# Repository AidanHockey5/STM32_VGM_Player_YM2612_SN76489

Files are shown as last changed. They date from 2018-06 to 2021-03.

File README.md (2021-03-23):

# This Version of the Project is now Deprecated
This is the old version of the Mega Blaster Project. Please visit this repo for the latest and greatest Mega Blaster 2 source material
https://github.com/AidanHockey5/MegaBlaster2

# Mega Blaster

See this project in action here: https://www.youtube.com/watch?v=WoAp2-gWaLM

For more information, visit: http://www.aidanlawrence.com/megablaster-hardware-sega-genesis-video-game-music-player/

This project is a hardware Video Game Music (VGM) player that uses a genuine YM2612 synthesizer chip + SN76489AN PSG. 
This project is driven by an STM32 "Blue Pill" board, chosen for it's ample speed, I/O, and best of all, price!

Included in this repository is the source code for the project, all of the schematic files, and a completed 
Ki-CAD printed circuit board /w Gerber files. Feel free to produce your own board!

PCB

# Information about the main sound chips and VGM

The YM2612 is a 6-channel FM synthesizer IC that was most prominently featured in the Sega Genesis (AKA Megadrive) home video game console. The YM2612 was also featured in the FM-Towns home computer and the Sega C2 Arcade System.
The YM2612 also had a CMOS alias that is functionally identical named the YM3438.
The SN76489 is a 3-channel + 1 noise channel programmable sound generator (PSG) that was popular with several early video game systems and home computers.
Most notably, the SN76489 was featured in the Sega Master system, the predecessor to the Genesis. To allow for backwards compatibility, Sega included a clone of the SN76489 in their new Genesis consoles.
Programmers and sound designers could leverage the SN76489 to add three more square wave channels to the YM2612's 6-channels of FM synth, creating 9 channels + 1 noise channels in total.
While this player was designed with the Genesis in mind, it can play back any VGM files designed for the Master System, FM-Towns PC, C2 machine, or any other machine that used the YM2612/YM3438 and/or the SN76489.
This project synthesizes music from .VGM files in real time on genuine hardware. There is no emulation here.

VGM stands for Video Game Music, and it is a 44.1KHz logging format that stores real soundchip register information. My player will parse these files and send the data to the appropriate chips. You can learn more about the VGM file format here: http://www.smspower.org/Music/VGMFileFormat

http://www.smspower.org/uploads/Music/vgmspec170.txt?sid=58da937e68300c059412b536d4db2ca0

# SD Card Information
This project is built for full-sized SD cards, but you may use adapters to fit your desired card. You must format your SD card to Fat32 in order for this device to work correctly. Your SD card must only contain uncompressed .vgm files. VGZ FILES WILL NOT WORK! You may download .vgz files and use [7zip](http://www.7-zip.org/download.html) to extract the uncompressed file out of them. Vgm files on the SD card do not need to have the .vgm extension. As long as they contain valid, uncompressed vgm data, they will be read by the program regardless of their name.
You can find VGM files by Googling "myGameName VGM," or by checking out sites like http://vgmrips.net/packs/

# Control Over Serial
You can use a serial connection to control playback features. The commands are as follows:

Command | Result
------------ | -------------
\+ | Next Track
\- | Previous Track
\* | Random Track
\/ | Toggle Shuffle Mode
\. | Toggle Song Looping
r: | Request song
? | What song is playing?
\! | Toggle the OLED display

A song request is formatted as follows: ```r:mySongFile.vgm```
Once a song request is sent through the serial console, an attempt will be made to open that song file. The file must exist on the SD card, and spelling/capitalization must be correct.
Need an easy-to-use serial console? [I've made one here.](https://github.com/AidanHockey5/OpenArduinoSerialConsole)

# Schematic
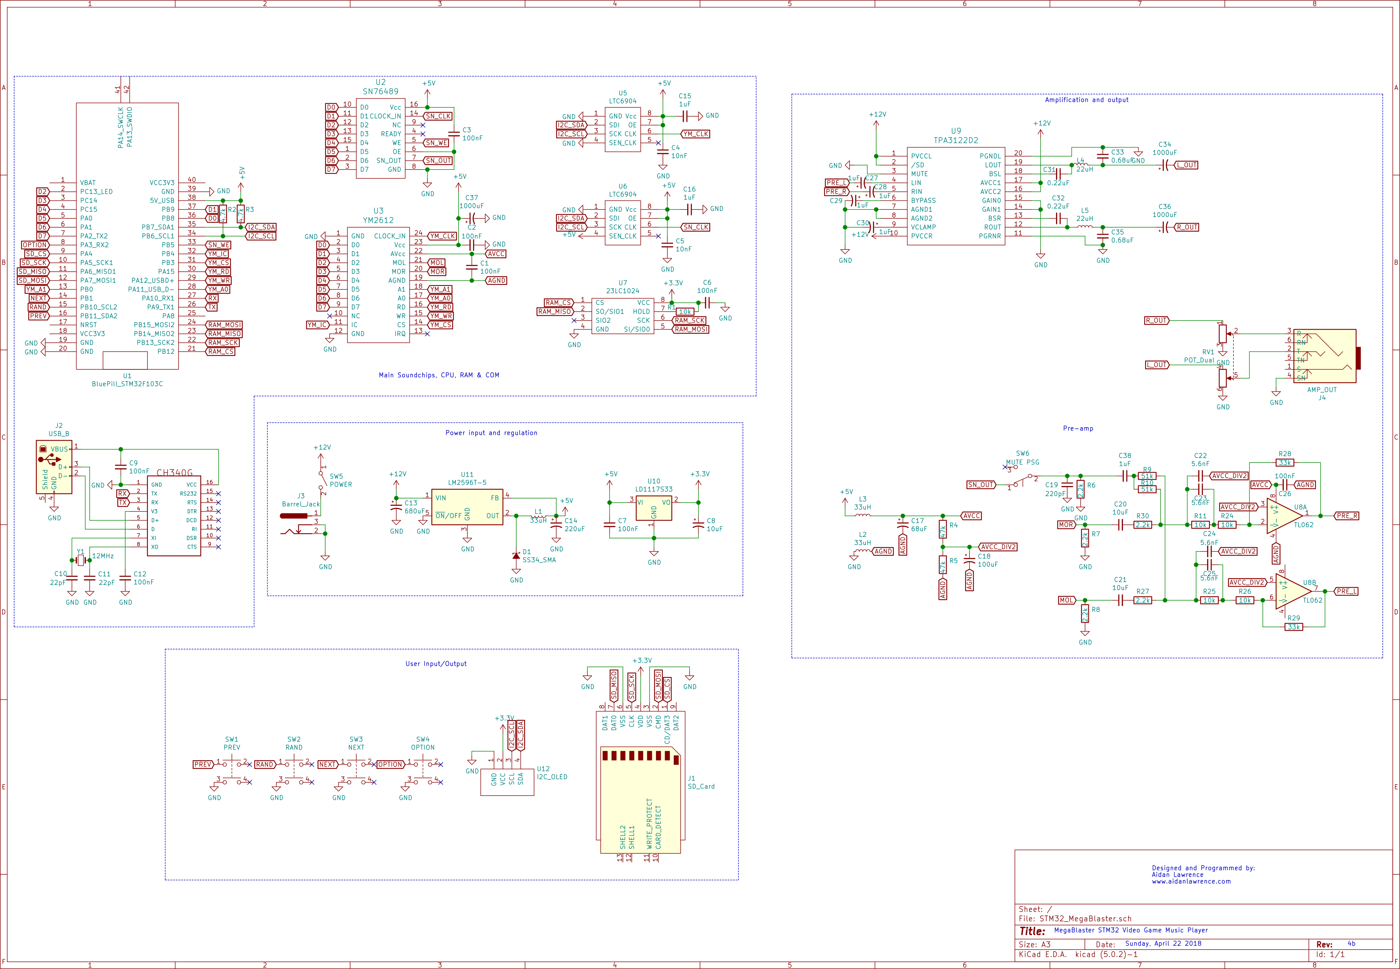
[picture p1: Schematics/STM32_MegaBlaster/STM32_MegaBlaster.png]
Schematic


[PDF](https://github.com/AidanHockey5/STM32_VGM_Player_YM2612_SN76489/raw/master/Schematics/STM32_MegaBlaster/STM32_MegaBlaster.pdf)

[Bill Of Materials (BOM)](https://github.com/AidanHockey5/STM32_VGM_Player_YM2612_SN76489/tree/master/Schematics/STM32_MegaBlaster/BOM)

# Interactive Assembly Guide
[You can view the interactive guide here.](https://www.aidanlawrence.com/wp-content/uploads/2018/09/ibom.html)

Courtesy of the stellar KiCAD plugin, [Interactive HTML BOM](https://github.com/openscopeproject/InteractiveHtmlBom)

Use this guide to help you assemble the Mega Blaster. Hover your cursor over the list of parts and this web page will show you where to place each component. I have included the source HTML file under the [Schematic's BOM folder](https://github.com/AidanHockey5/STM32_VGM_Player_YM2612_SN76489/tree/master/Schematics/STM32_MegaBlaster/BOM) for local viewing. 

# Programming

Programming must be done through the built-in serial port. YOU CAN NOT USE AN STLINK FOR PROGRAMMING.

You have two programming options: Using the flashing tool OR flashing from source.

[DOWNLOAD THE FLASHING TOOL HERE](https://www.aidanlawrence.com/tools/ee/megablaster/MegaFlasher_MB.zip)

Windows users can just use the pre-compiled Flash.exe program to skip worrying about Python installs or dependancies.
All other operating system users can simply run the Flash.py script using Python 3.0+.

Read the Readme file included with the tool for usage instructions and python dependancies.

I have also made a quick video guide on how to program the MegaBlaster from source. It's pretty simple!

https://youtu.be/sSx3_d5n6gs

1) Set the "Bluepill" left jumper to the '1' position.
2) Turn on the MegaBlaster
3) Hit the reset button on the Bluepill board.
4) Open the source code in Visual Studio Code /w the PlatformIO extension.
5) Upload the code using the upload button on the bottom ribbon.
6) Replace the jumper on the Bluepill board to it's original '0' position.

Link to VS Code: https://code.visualstudio.com/

PlatformIO install guide: http://docs.platformio.org/en/latest/ide/vscode.html#installation 

PlatformIO Not finding your serial port? Try opening up your Platformio.ini file and adding the following lines:
```
upload_port = COMX

upload_protocol = serial
```

(Make sure to change 'X' to the number of your COM port that the MegaBlaster is connected to. (I.E. COM4, COM8, COM10, etc.)

# KiCad
The schematic and PCB of this project was made in a nightly version of KiCad 5, specifically, 5.0.0 RC2 (dev-493-gd776eaca8)
Since then, the project has been migrated to KiCAD 5 stable.
Please download the latest stable release of KiCAD 5 here: http://kicad-pcb.org/download/

# YM3438 Support
After a little tinkering, I've managed to get a YM3438 working as a replacement for the YM2612. For those that don't know, the YM3438 is functionally equivalent to the YM2612, but is made using a CMOS process. The YM3438 is pin-compatible but it is not a drop-in replacement since the output impedance is significantly higher. Fortunately, all you need to do to get a YM3438 to work is mod a couple resistors.

Resistor Number | Replace with
------------ | -------------
R7 | LEAVE UNPOPULATED
R8 | LEAVE UNPOPULATED
R6 | 1.2K
R9 | 100K
R10 | 100K
R27 | 33K
R30 | 33K
R28 | 150K
R29 | 150K

WARNING! The final sound output volume will be SIGNIFICANTLY HIGHER with this setup. Be sure to start your YM3438 MegaBlaster at the lowest possible volume before turning on the device and slowly increase the volume to prevent equipment damage and or hearing damage.

Why replace the YM2612 with a YM3438? Well, for one, the YM3438 runs very cool while the YM2612s typically get screaming hot during normal operation. The sound quality is also slightly altered with FM synths typically sounding a little more 'sterile' compared to the YM2612's characteristic grit. PCM sample quality is also significantly improved. Later revisions of the Sega Genesis used an ASIC YM3438 instead of a discrete YM2612, so some users may be more familiar with the likes of the YM3438 than the YM2612. It's all personal preference really.

You can see a YM2612/YM3438 comparison video here: https://www.youtube.com/watch?v=jMHRtriv1wM

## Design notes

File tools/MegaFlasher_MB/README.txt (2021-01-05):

NO DEPENDANCIES OR PYTHON INSTALL REQUIRED FOR WINDOWS EXE

PYTHON DEPENDANCIES:
Python 3.0+
pyserial
requests

Enter the following commands:

pip install pyserial
pip install requests

Run:
python3 Flash.py

----------------------------------------------

Instructions for use:

On the MEGABLASTER DEVICE: Move the left jumper pin at the top of the board to the "UP" position.
It should look like this:
https://www.aidanlawrence.com/wp-content/uploads/2021/01/mb_jumper-scaled.jpg

Plug-in your MEGABLASTER to your computer via USB and apply 12V to the power jack.

Switch the unit ON.

Press the RESET BUTTON.

Run the Flash.exe program OR run Flash.py with Python.

Select the COM port of the MEGABLASTER.

If everything is correct, your system should automatically download the firmware file and flash.

After flashing, replace the jumper's position back to DOWN.

----------------------------------------------

EXE Built with pyinstaller
pyinstaller --onefile Flash.py

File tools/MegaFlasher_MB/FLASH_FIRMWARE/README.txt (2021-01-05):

stm32flash 0.5

This binary is for Microsoft Windows 64-bit

It was built using MinGW-64 from MSYS2 with gcc 5.3.0,
for build instructions please see:
https://sourceforge.net/p/stm32flash/wiki/Build/

Source code:
https://sourceforge.net/p/stm32flash/code/ci/v0.5/tree/

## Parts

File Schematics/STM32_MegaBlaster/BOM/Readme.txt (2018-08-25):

I've tried to keep as many components on Digikey as possible, but obviously, not everything will be on there.
That means that if you'd like a complete order of components, you must have all of the components from the DIGIKEY-BOM.csv file AND the EXTERNAL_BOM_ITEMS.txt list.

For items like resistors: Bog-standard 1/4 watt (the most common sizes you'd normally find in kits) will work, but I tried to track some down on Digikey any ways. 

For items listed on Aliexpress: Shop around and do your research. The links I provided should give you a great head start. Also check sources like eBay for similar goods.
LCSC can also provide parts at a significantly lower price than Digikey, but their selection is not as good. If you order a PCB from JLCPCB, you can ship components from LCSC combined for free.

You can use the Digikey BOM import tool to make this entire process much faster: https://www.digikey.com/BOM
Or you can sign-in to Digikey and view the parts cart here: https://www.digikey.com/short/jf18pj

Also, the 1000uF capacitors (C37, C36, and C34) are actually have 2.5mm pin spacing, but Digikey only had 3.5mm spaced 8mm diameter caps. The fit isn't exactly perfect, but it's close enough to work.
If you can find 1000uF (16V or higher) capacitors that are 8mm in diameter and have 2.5mm pin spacing, I reccomend that you use those for a better fit.

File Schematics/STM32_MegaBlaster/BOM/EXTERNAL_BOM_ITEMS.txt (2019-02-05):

1x - J4 - AMP_OUT - PJ320E_3.5mm_Jack - https://www.aliexpress.com/wholesale?catId=0&initiative_id=SB_20180518120441&SearchText=PJ-320E
1x - RV1 - POT_Dual - LOG-10k DUAL GANG POTENTIOMETER - https://www.adafruit.com/product/3394
1x - U4 - CH340G - https://lcsc.com/product-detail/USB_CH340G_C14267.html 
1x - U1 - STM32 Bluepill Board - https://www.aliexpress.com/wholesale?catId=0&initiative_id=SB_20180518120532&SearchText=STM32F103C8T6
1x - U2 - SN76489AN - https://www.aliexpress.com/wholesale?catId=0&initiative_id=SB_20180518120553&SearchText=SN76489
1x - U3 - YM2612 - https://www.aliexpress.com/wholesale?catId=0&initiative_id=SB_20180518120658&SearchText=YM2612
1x - U12 - I2C OLED 1.3in. SH1106 - https://www.aliexpress.com/wholesale?catId=0&initiative_id=SB_20180518121221&SearchText=I2C+OLED+1.3

[[[OLED WARNING! Check for SH1106, not SSD1306. Check pin order! Pin order must be: GND, VCC, SCL(SCK), SDA. Most OLEDs feature a set of jumper resistors on the back to adjust these pins should you order a display with an incorrect pin configuration.]]]

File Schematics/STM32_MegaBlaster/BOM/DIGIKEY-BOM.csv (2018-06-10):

Manufacturer Part Number | Manufacturer | Digi-Key Part Number | Customer Reference | Reference Designator | Packaging | Part Status | Quantity | Unit Price | Extended Price | Quantity Available | Mfg Std Lead Time | Description | RoHS Status | Lead Free Status | REACH Status
UPJ1E680MED1TD | Nichicon | 493-5039-1-ND |  |  | Cut Tape (CT) | Active | 1 | 0.31000 | $0.31 | 4990 | 18 Weeks | CAP ALUM 68UF 20% 25V RADIAL | RoHS Compliant | Lead free | REACH Unaffected
RDE5C1H562J1K1H03B | Murata Electronics North America | 490-8704-ND |  |  | Bulk | Active | 4 | 0.49000 | $1.96 | 1129 | 11 Weeks | CAP CER 5600PF 50V NP0 RADIAL | RoHS Compliant | Lead free | REACH Unaffected
AIUR-16-330K | Abracon LLC | AIUR-16-330K-ND |  |  | Box | Active | 3 | 0.78000 | $2.34 | 868 | 11 Weeks | FIXED IND 33UH 800MA 90 MOHM TH | RoHS Compliant | Lead free | REACH Unaffected
16ZLH680MEFC10X12.5 | Rubycon | 1189-1150-ND |  |  | Bulk | Active | 1 | 0.43000 | $0.43 | 6103 | 17 Weeks | CAP ALUM 680UF 20% 16V RADIAL | RoHS Compliant | Lead free | REACH Unaffected
0670688011 | Molex, LLC | WM12785-ND |  |  | Tube | Active | 1 | 2.06000 | $2.06 | 1590 | 12 Weeks | USB B CONN WITH KINK BOARD LOCK | RoHS Compliant | Lead free | REACH Unaffected
1825115-1 | TE Connectivity ALCOSWITCH Switches | 450-1598-ND |  |  | Bulk | Active | 2 | 0.98000 | $1.96 | 3119 | 4 Weeks | SWITCH SLIDE SPDT 250MA 125V | RoHS Compliant | Lead free | Not Available
2041021-4 | TE Connectivity AMP Connectors | A101492CT-ND |  |  | Cut Tape (CT) | Active | 1 | 3.44000 | $3.44 | 2777 | 11 Weeks | CONN SD CARD PUSH-PULL R/A SMD | RoHS Compliant | Lead free | Not Available
PJ-002A | CUI Inc. | CP-002A-ND |  |  | Bag | Active | 1 | 0.60000 | $0.60 | 113742 | Not Available | CONN PWR JACK 2X5.5MM SOLDER | RoHS Compliant | Lead free | Not Available
TL062CP | Texas Instruments | 296-1771-5-ND |  |  | Tube | Active | 1 | 0.69000 | $0.69 | 3889 | 13 Weeks | IC OPAMP JFET 1MHZ 8DIP | RoHS Compliant | Lead free | REACH Unaffected
K104Z15Y5VF5TL2 | Vishay BC Components | BC1160CT-ND |  |  | Cut Tape (CT) | Active | 8 | 0.19000 | $1.52 | 78547 | 8 Weeks | CAP CER 0.1UF 50V Y5V RADIAL | RoHS Compliant | Lead free | Not Available
K103K15X7RF5TL2 | Vishay BC Components | BC1078CT-ND |  |  | Cut Tape (CT) | Active | 2 | 0.19000 | $0.38 | 9972 | 8 Weeks | CAP CER 10000PF 50V X7R RADIAL | RoHS Compliant | Lead free | Not Available
UMA1C100MDD1TP | Nichicon | 493-10458-1-ND |  |  | Cut Tape (CT) | Active | 1 | 0.28000 | $0.28 | 7221 | 21 Weeks | CAP ALUM 10UF 20% 16V RADIAL | RoHS Compliant | Lead free | REACH Unaffected
K220J15C0GF5TL2 | Vishay BC Components | BC1005CT-ND |  |  | Cut Tape (CT) | Active | 2 | 0.21000 | $0.42 | 93566 | 8 Weeks | CAP CER 22PF 50V C0G/NP0 RADIAL | RoHS Compliant | Lead free | Not Available
UVY1C221MED1TD | Nichicon | 493-12895-1-ND |  |  | Cut Tape (CT) | Active | 1 | 0.31000 | $0.31 | 4437 | 18 Weeks | CAP ALUM 220UF 20% 16V RADIAL | RoHS Compliant | Lead free | REACH Unaffected
FG28X7R1E105KRT06 | TDK Corporation | 445-173583-1-ND |  |  | Cut Tape (CT) | Active | 3 | 0.32000 | $0.96 | 4648 | 16 Weeks | CAP CER 1UF 25V X7R RADIAL | RoHS Compliant | Lead free | REACH Unaffected
ECA-1CM101 | Panasonic Electronic Components | P5138-ND |  |  | Bulk | Active | 1 | 0.22000 | $0.22 | 5184 | 15 Weeks | CAP ALUM 100UF 20% 16V RADIAL | RoHS Compliant | Lead free | REACH Unaffected
FA28C0G2E221JNU06 | TDK Corporation | 445-174276-1-ND |  |  | Cut Tape (CT) | Active | 1 | 0.50000 | $0.50 | 5597 | 16 Weeks | CAP CER 220PF 250V NP0 RADIAL | RoHS Compliant | Lead free | REACH Unaffected
FG24X7R1A106KRT06 | TDK Corporation | 445-173370-1-ND |  |  | Cut Tape (CT) | Active | 2 | 0.58000 | $1.16 | 1831 | 16 Weeks | CAP CER 10UF 10V X7R RADIAL | RoHS Compliant | Lead free | REACH Unaffected
UMF1V010MDD1TP | Nichicon | 493-10230-1-ND |  |  | Cut Tape (CT) | Active | 4 | 0.45000 | $1.80 | 2110 | 21 Weeks | CAP ALUM 1UF 20% 35V RADIAL | RoHS Compliant | Lead free | REACH Unaffected
FG24X7R1H224KNT06 | TDK Corporation | 445-173377-1-ND |  |  | Cut Tape (CT) | Active | 2 | 0.29000 | $0.58 | 4783 | 16 Weeks | CAP CER 0.22UF 50V X7R RADIAL | RoHS Compliant | Lead free | REACH Unaffected
FA28X7R1H683KNU06 | TDK Corporation | 445-175032-1-ND |  |  | Cut Tape (CT) | Active | 2 | 0.41000 | $0.82 | 3940 | 16 Weeks | CAP CER 0.068UF 50V X7R RADIAL | RoHS Compliant | Lead free | REACH Unaffected
CDBA140-G | Comchip Technology | 641-1015-1-ND |  |  | Cut Tape (CT) | Active | 1 | 0.37000 | $0.37 | 339890 | 16 Weeks | DIODE SCHOTTKY 40V 1A DO214AC | RoHS Compliant | Lead free | REACH Unaffected
RNF14FTD10K0 | Stackpole Electronics Inc. | RNF14FTD10K0CT-ND |  |  | Cut Tape (CT) | Active | 5 | 0.10000 | $0.50 | 182883 | 13 Weeks | RES 10K OHM 1/4W 1% AXIAL | RoHS Compliant | Lead free | REACH Unaffected
CF14JT4K70 | Stackpole Electronics Inc. | CF14JT4K70CT-ND |  |  | Cut Tape (CT) | Active | 2 | 0.10000 | $0.20 | 299143 | 14 Weeks | RES 4.7K OHM 1/4W 5% AXIAL | RoHS Compliant | Lead free | REACH Unaffected
CF14JT47K0 | Stackpole Electronics Inc. | CF14JT47K0CT-ND |  |  | Cut Tape (CT) | Active | 2 | 0.10000 | $0.20 | 186504 | 14 Weeks | RES 47K OHM 1/4W 5% AXIAL | RoHS Compliant | Lead free | REACH Unaffected
CF14JT2K20 | Stackpole Electronics Inc. | CF14JT2K20CT-ND |  |  | Cut Tape (CT) | Active | 5 | 0.10000 | $0.50 | 144923 | 14 Weeks | RES 2.2K OHM 1/4W 5% AXIAL | RoHS Compliant | Lead free | REACH Unaffected
CF14JT51K0 | Stackpole Electronics Inc. | CF14JT51K0CT-ND |  |  | Cut Tape (CT) | Active | 2 | 0.10000 | $0.20 | 19213 | 14 Weeks | RES 51K OHM 1/4W 5% AXIAL | RoHS Compliant | Lead free | REACH Unaffected
CF14JT33K0 | Stackpole Electronics Inc. | CF14JT33K0CT-ND |  |  | Cut Tape (CT) | Active | 2 | 0.10000 | $0.20 | 185584 | 14 Weeks | RES 33K OHM 1/4W 5% AXIAL | RoHS Compliant | Lead free | REACH Unaffected
B3F-1060 | Omron Electronics Inc-EMC Div | SW1177-ND |  |  | Bulk | Active | 4 | 0.34000 | $1.36 | 2711 | 11 Weeks | SWITCH TACTILE SPST-NO 0.05A 24V | RoHS Compliant | Lead free | Not Available
A 24-LC-TT | Assmann WSW Components | AE10001-ND |  |  | Tube | Active | 1 | 0.35000 | $0.35 | 6647 | 20 Weeks | CONN IC DIP SOCKET 24POS TIN | RoHS Compliant | Lead free | REACH Unaffected
A 16-LC-TT | Assmann WSW Components | AE9992-ND |  |  | Tube | Active | 1 | 0.25000 | $0.25 | 38380 | 20 Weeks | CONN IC DIP SOCKET 16POS TIN | RoHS Compliant | Lead free | REACH Unaffected
A 08-LC-TT | Assmann WSW Components | AE9986-ND |  |  | Tube | Active | 2 | 0.18000 | $0.36 | 87482 | 20 Weeks | CONN IC DIP SOCKET 8POS TIN | RoHS Compliant | Lead free | REACH Unaffected
A 20-LC-TT | Assmann WSW Components | AE9998-ND |  |  | Tube | Active | 1 | 0.29000 | $0.29 | 44887 | 20 Weeks | CONN IC DIP SOCKET 20POS TIN | RoHS Compliant | Lead free | REACH Unaffected
LTC6904CMS8#PBF | Linear Technology/Analog Devices | LTC6904CMS8#PBF-ND |  |  | Tube | Active | 2 | 4.31000 | $8.62 | 1595 | 8 Weeks | IC OSC SILICON PROG 8-MSOP | RoHS Compliant | Lead free | REACH Unaffected
23LC1024-I/P | Microchip Technology | 23LC1024-I/P-ND |  |  | Tube | Active | 1 | 2.22000 | $2.22 | 297 | 5 Weeks | IC SRAM 1MBIT 20MHZ 8DIP | RoHS Compliant | Lead free | REACH Unaffected
TPA3122D2N | Texas Instruments | 296-23375-5-ND |  |  | Tube | Active | 1 | 3.31000 | $3.31 | 421 | 6 Weeks | IC AMP AUDIO PWR 15W STER 20DIP | RoHS Compliant | Lead free | REACH Unaffected
LD1117S33TR | STMicroelectronics | 497-1242-1-ND |  |  | Cut Tape (CT) | Active | 1 | 0.42000 | $0.42 | 0 | Not Available | IC REG LINEAR 3.3V 800MA SOT223 | RoHS Compliant | Lead free | Not Available
LM2596S-5.0/NOPB | Texas Instruments | LM2596S-5.0/NOPB-ND |  |  | Tube | Active | 1 | 5.72000 | $5.72 | 0 | 30 Weeks | IC REG BUCK 5V 3A TO263-5 | RoHS Compliant | Contains lead | REACH Unaffected
ECS-120-20-4 | ECS Inc. | X227-ND |  |  | Bulk | Active | 1 | 0.69000 | $0.69 | 1635 | 9 Weeks | CRYSTAL 12.0000MHZ 20PF T/H | RoHS non-compliant | Contains lead | REACH Unaffected
UHV1C102MPD6 | Nichicon | 493-16434-ND |  |  | Bulk | Active | 3 | 0.65000 | $1.95 | 677 | 20 Weeks | CAP ALUM 1000UF 20% 16V RADIAL | RoHS Compliant | Lead free | REACH Unaffected
RLB1014-222KL | Bourns Inc. | RLB1014-222KL-ND |  |  | Bag | Active | 2 | 0.43000 | $0.86 | 1019 | 20 Weeks | FIXED IND 2.2MH 110MA 8.4 OHM TH | RoHS Compliant | Lead free | REACH Unaffected

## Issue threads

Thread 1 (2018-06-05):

OSH Park Unsupported Drilled Slots

sparksterz, 2018-06-05:
Hey, I was looking to build one of these, but having no knowledge of PCB layout and tools to generate them with I'm wondering if this is something to be concerned about.

Unfortunately they don't really give much info on which slots...and it's flagged as just a warning. I'm able to generate this by uploading the zipped gerber files. using the kicad_pcb file directly doesn't seem compatible. I assume due to the version of kicad being newer? Not sure.

Here is the information they give me from the zipped gerber files:

Processing information
* Processing Megablaster_Gerber.zip as KiCad ZIP file.
* 2 layer board of 5.46x3.61 inches.
* Your project contains 2 drill files, we've merged them. ["STM32_MegaBlaster-NPTH.drl", "STM32_MegaBlaster-PTH.drl"]

Warning (non-critical)
* Detected unsupported drilled slots.

As far as I can tell by their thumbnail board renders this might be the slots near the DC power jack and/or maybe the audio jack? They seem to look a bit strange on their generated image. Here's the [link to the image that was generated](https://644db4de3505c40a0444-327723bce298e3ff5813fb42baeefbaa.ssl.cf1.rackcdn.com/67f2c8f53406d2f81542bcc66bbe4da2.png)

Is there another preferred vendor to use? I know a minor amount about electronics from bread board type work, but nothing about prefabricated PCBs.

AidanHockey5, 2018-06-05:
Hello Brian!

Yep! It's a good thing you caught that because your DC jack wouldn't fit
with holes like that!

I recommend using JLCPCB - it's who I went with for this project. They'll
give your more boards for less money to boot. The zipped Gerber files I
created are to their specifications, so they should work without a hitch.

Let me know if you have any more questions!

-Aidan

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

Closed 2018-06-07.

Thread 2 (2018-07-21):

Some tunes with heavy (drum) samples usage slow down the replay speed

rylecqfd, 2018-07-21:
Hi

It seems that some tunes that make heavy use of (drum) samples have their speed slowed down each time a sample is played.

Here is one example:  [Matt Furniss - The Terminator](http://project2612.org/download.php?id=181).

AidanHockey5, 2018-07-22:
Yep, that is a known limitation of the hardware. The tracks you have picked are by an artist who is known for pushing the Genesis' musical hardware to its limits, so my little player is probably not going to be able to keep up with the heavy usage of PCM samples.

Most VGM files will play back at full speed regardless of their PCM sampling. Just a few particular PCM-heavy tracks saturate the data bus and prevent full-speed playback.

One particular torture test that I like to use is actually Green Hill Zone from Sonic the Hedgehog. That track's PCM drums often brought my previous prototypes to their knees. The MegaBlaster can keep up for the most part, but the tempo still lags behind just a bit. I'd be interested to see if anybody could modify the firmware to write PCM samples faster than what I have here!

natarii, 2018-10-21:
This is an old issue, but I briefly looked at your code, and while I don't have any STM32 hardware to test this on, I suspect you are running into this problem due to the overhead of setting up and tearing down the SPI transfer from the SRAM for every sample.

I am working on a similar project and it is able to play these files without any speed issues. My solution is instead of using a large chunk of RAM, use relatively small buffers (a few K) and load the VGM file using separate streams into two FIFOs: one for raw VGM commands, the other for the attached PCM data. When reading an 0x8n command from the file, calculate the offset of that sample and read it into the PCM FIFO before inserting the 0x8n command into the VGM FIFO. This way, during playback, when you hit an 0x8n you can just pull the first sample out of the PCM FIFO.

Possible complications:
- Your code will likely need some reworking, as your playback loop appears to directly read the file and then write to the chip with no buffering in between.
- I believe the SdFat library uses a single SD card buffer, rather than one per File object. You may need to implement your own buffer to wrap around File.read(), otherwise performance will get killed from all the seeking. A multiple of the SD card's sector size may be a good starting point.
- From your schematic, the SD card is hooked up in 1-bit mode. I don't know offhand if this is fast enough to playback PCM data in realtime. 4-bit mode certainly is...

That being said, it's probably worth dealing with this to get the ability to play "busy" VGMs, and also VGMs that have more PCM data than would fit in the SRAM.

Here are some demo videos of playing a few of the tracks mentioned in this issue. Just recorded real quickly with my phone camera, but you get the idea. This technique is being used.
https://youtu.be/QawYF8nzBoE
https://youtu.be/OeX5HKd4tyY

Links to my project source. The relevant parts will be in loader.c and driver.c: https://git.agiri.ninja/natalie/megagrrl/blob/master/main/loader.c
https://git.agiri.ninja/natalie/megagrrl/blob/master/main/driver.c

If you contact me off GitHub I can also provide further pointers on implementing this, or VGM DAC stream control support!

AidanHockey5, 2018-10-26:
I think there is a chance that performance could be significantly improved via software, but it would require a pretty extensive rewrite. Implementing a buffering system like @natarii would be pretty tricky, but it would likely drastically improve PCM playback speeds.
I'm still of the opinion though that I'm a bit hardware limited, so I may need to rethink some of my board layout too.
Either way though, I think rewriting the software for this project is a definite goal of mine, so I'll see what I can do in that regard.

piklz, 2018-10-26:
That would be awesome both of you working together would be neat ! I'm going to order your bom/pcs etc  anyway and make the current version so hopefully any improvements will be greatly appreciated!

natarii, 2018-10-26:
Hi, sorry, I didn't check GitHub for a few days.

I ordered an STM32 Blue Pill board to play with. I didn't realize it had "only" 20K of RAM, but I have a feeling this is still doable on it. My earlier experiments in this project were on an ATmega2560, a Teensy 3.6, and finally an ESP32, so yeah I've gone through several revisions as well. Everything I've done was also doable on the Teensy 3.6, just a bit hackier because it doesn't have the luxury of the ESP32's second core and all the FreeRTOS queues and stuff to pass data around.

Unsure about whether 1-bit SD mode will be fast enough to do this in realtime. A lot of VGMs seem to have tons of redundant register writes when playing PCM, and you may be looking at a requirement of 150KB/s+ read speed to be able to handle it. I think this is well within the theoretical read speed, but it may work out differently in practice, and/or be dependent on the specific card. Getting rid of the SPI RAM may free up enough IOs to use the card in 4-bit mode, assuming there are no restrictions on which pins can be used for that. (Lack of IOs pushed me to use shift registers for the sound chip bus on the ESP32, but I'm also hitting them pretty fast at 20+ MHz)

You'll probably want to move the actual chip output stuff into a timer interrupt, and either get a library or write from scratch some ISR-safe FIFOs. You can also just disable timer interrupts when sticking new data into the FIFOs although that isn't quite as clean.

If you want to collab on anything, let me know, I'd enjoy that. I can also get you a schematic of my hardware, only haven't put it in git yet because there are a few minor errors that need to be fixed, although they're related to power supply stuff rather than anything VGM-related

AidanHockey5, 2018-10-26:
I'd love to collaborate! I'm really interested in seeing how you'd approach this on a blue-pill board. The RAM requirements really make buffering systems tough to pull off. I think the ESP32 has something along the lines of 520KB of RAM (wow) which would be an absolute luxury for me. Buffering out FM+PSG data shouldn't really be an issue, but as always, once PCM samples come into play, the game changes a bit.
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
AidanHockey5, 2018-11-05:
Hey everyone, I have just rewritten the firmware from scratch. Version 2 is up and ready to go.
Here are the notes on my changes: https://github.com/AidanHockey5/STM32_VGM_Player_YM2612_SN76489/pull/3

Playback speed has been significantly improved, though, there are still limitations with the hardware that are keeping me from playing songs like The Terminator tracks listed above. I simply don't have enough RAM to keep everything cached away in buffers and since my SD card is in 1-bit mode, I can't replenish the buffers fast enough to keep in time. Therefore, unless there is someone out there that can perform some serious magic, I think this is about as good as it's going to get for this iteration of the hardware.

For all the other tracks with more reasonable PCM sessions, this new version is night-and-day better!

krsshtx, 2019-12-30:
Hi Aidan!
Can you check playback of this ost?
https://project2612.org/details.php?id=124

AidanHockey5, 2019-12-30:
Hello krsshtx,

Battletoads is infamously difficult to play back, so it's unlikely that my player would be able to render it without any slowdown. A project that _can_ handle that OST would be Natalie's MegaGRRL player! https://kunoichilabs.dev/

krsshtx, 2019-12-31:
> Battletoads is infamously difficult to play back, so it's unlikely that my player would be able to render it without any slowdown.

Looks like it's more complex - beeping on some tracks and tempo drift on others .

I have another strange issue. Clicking sound instead of drums in high seas havoc o_O
No drums at all.

https://project2612.org/details.php?id=343

krsshtx, 2020-01-05:
case 0x4F:
case 0x50:
case 0x52:
case 0x53:
***
return 1
1:  1/44100 = 22675,736961451ns

ym2203 pdf:
Address set-up time 10ns min
Write data setup time 100ns min
Write pulse write width 200ns min

krsshtx, 2020-01-12:
re-mix
https://github.com/krsshtx/YM

AidanHockey5, 2021-01-01:
#6
At long last with much trial and error, this issue has been fixed. The reason behind it was mostly due to a misunderstanding I had with how VGM data was supposed to be parsed. Instead of literally taking one sample every 1/44100th of a second, you are supposed to write entire blocks of data to the chips as soon as possible and ONLY tick delay commands at 44100Hz.

Early tests seem stable enough. Even write-heavy tracks like ones from The Terminator OST seem to work admirably.

Sorry for the delay on fixing this! I thought it couldn't be fixed.

Hey, at least @natarii was the best thing to come out of this issue, haha.

krsshtx, 2021-03-08:
>I thought it couldn't be fixed.

Хорошо, что не сдался.
Как насчёт ym2608?

krsshtx, 2021-03-10:
From the other side...

As I thought you've abandoned your project and I had a non-working properly device which I really loved I had no choice but to re-mix your code.

Your words "A project that can handle that OST would be Natalie's MegaGRRL player!" confused me a lot. Dissapointed a lot.
M68K/Z80 was able, but STM32 can't. Lets see..

I'am not a programmer. And had no knowledge in arduino ide and stm32 at all.
After a lot of building/uploading and making lpt 2612 device to test i've made a working build which played high seas havoc, rocket knight adventures, terminator and even battletoads which you've mentioned as unplayable. It took much time.
Your code was:

 if(waitSamples == 0 && !samplePlaying)
  {
    samplePlaying = true;
    waitSamples += parseVGM();

Mine:

 while(waitSamples == 0 )
  {
   waitSamples += parseVGM();
   waitstate=false;

Your:

    case 0x52:
    {
    uint8_t addr = readBuffer();
    uint8_t data = readBuffer();
    ym2612.Send(addr, data, 0);
    }
    return 1;
    case 0x53:
    {
    uint8_t addr = readBuffer();
    uint8_t data = readBuffer();
    ym2612.Send(addr, data, 1);
    }
    return 1;

Mine:

     case 0x52:
    {
     addr = readBuffer();
     data = readBuffer();
     ym2612.Read();
    ym2612.Send(addr, data, 0);

    }
    return 0;
    case 0x53:
    {
     addr = readBuffer();
     data = readBuffer();
        ym2612.Read();
    ym2612.Send(addr, data, 1);

    }
    return 0;

It was even neccesary to make ym_read function. Because it became too fast.

And now you've changed your mind telling "@natarii was the best thing" and started to sell it.

I am very impressed not to say more.

Closed 2021-01-01.

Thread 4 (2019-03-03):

Build issues (Win 10 x64) Missing build steps?

sparksterz, 2019-03-03:
I've recently assembled my board but am unable to build/upload the project. I have the latest VS Code and recently installed Platform IO. I've made/logged in with my account, but when trying to run a build or upload I am having issues.

The first of which was that `U8g2lib.h` was not recognized. Within platform io I downloaded u8g2 and that seems to have resolved that issue. The other however I'm unsure of. They all seem related but I don't understand what the errors mean.

Here's the error console

```
Processing genericSTM32F103C8 (platform: ststm32@~4.5.0; board: genericSTM32F103C8; framework: arduino)
-----------------------------------------------------------------------------------------------
Verbose mode can be enabled via `-v, --verbose` option
CONFIGURATION: https://docs.platformio.org/page/boards/ststm32/genericSTM32F103C8.html
PLATFORM: ST STM32 > STM32F103C8 (20k RAM. 64k Flash)
HARDWARE: STM32F103C8T6 72MHz 20KB RAM (64KB Flash)
DEBUG: CURRENT(blackmagic) EXTERNAL(blackmagic, jlink, stlink)
Library Dependency Finder -> http://bit.ly/configure-pio-ldf
LDF MODES: FINDER(chain) COMPATIBILITY(soft)
Collected 33 compatible libraries
Scanning dependencies...
Dependency Graph
|-- <Wire> 1.0
|-- <U8g2> 2.26.1
|   |-- <Wire> 1.0
|   |-- <SPI> 1.0
|-- <SPI> 1.0
|-- <SdFat> 1.0.3
|   |-- <SPI> 1.0
Compiling .pioenvs\genericSTM32F103C8\src\Bus.cpp.o
Compiling .pioenvs\genericSTM32F103C8\src\LTC6904.cpp.o
Compiling .pioenvs\genericSTM32F103C8\src\SN76489.cpp.o
Compiling .pioenvs\genericSTM32F103C8\src\SPIRAM.cpp.o
Compiling .pioenvs\genericSTM32F103C8\src\YM2612.cpp.o
Compiling .pioenvs\genericSTM32F103C8\src\main.cpp.o
Compiling .pioenvs\genericSTM32F103C8\lib980\Wire\SoftWire.cpp.o
Compiling .pioenvs\genericSTM32F103C8\lib980\Wire\Wire.cpp.o
In file included from c:\users\bking\.platformio\packages\toolchain-gccarmnoneeabi\arm-none-eabi\include\stdlib.h:19,
from c:\users\bking\.platformio\packages\toolchain-gccarmnoneeabi\arm-none-eabi\include\c++\8.2.1\cstdlib:75,
from c:\users\bking\.platformio\packages\toolchain-gccarmnoneeabi\arm-none-eabi\include\c++\8.2.1\stdlib.h:36,
from C:\Users\bking\.platformio\packages\framework-arduinoststm32\STM32F1\cores\maple/wirish.h:41,
from C:\Users\bking\.platformio\packages\framework-arduinoststm32\STM32F1\cores\maple/Arduino.h:30,
from src\LTC6904.cpp:2:
C:\Users\bking\.platformio\packages\framework-arduinoststm32\STM32F1\system\libmaple/stm32f1/include/series/gpio.h:489:15: error: duplicate 'inline'
static inline __always_inline void afio_exti_select(exti_num exti, exti_cfg port) {
^~~~~~~~~~~~~~~
C:\Users\bking\.platformio\packages\framework-arduinoststm32\STM32F1\system\libmaple\include/libmaple/nvic.h:112:15: error: duplicate 'inline'
static inline __always_inline void nvic_globalirq_enable() {
^~~~~~~~~~~~~~~
C:\Users\bking\.platformio\packages\framework-arduinoststm32\STM32F1\system\libmaple\include/libmaple/nvic.h:119:15: error: duplicate 'inline'
static inline __always_inline void nvic_globalirq_disable() {
^~~~~~~~~~~~~~~
C:\Users\bking\.platformio\packages\framework-arduinoststm32\STM32F1\cores\maple/ext_interrupts.h:109:15: error: duplicate 'inline'
static inline __always_inline void interrupts() {
^~~~~~~~~~~~~~~
C:\Users\bking\.platformio\packages\framework-arduinoststm32\STM32F1\cores\maple/ext_interrupts.h:123:15: error: duplicate 'inline'
static inline __always_inline void noInterrupts() {
^~~~~~~~~~~~~~~
In file included from c:\users\bking\.platformio\packages\toolchain-gccarmnoneeabi\arm-none-eabi\include\stdlib.h:19,
from c:\users\bking\.platformio\packages\toolchain-gccarmnoneeabi\arm-none-eabi\include\c++\8.2.1\cstdlib:75,
from c:\users\bking\.platformio\packages\toolchain-gccarmnoneeabi\arm-none-eabi\include\c++\8.2.1\stdlib.h:36,
Cfompiling .pioenvs\genericSTM32F103C8\lib980\Wire\utility\WireBase.cpp.orom C:\Users\bking\.platformio\packages\framework-arduinoststm32\STM32F1\cores\maple/wirish.h:41,
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
AidanHockey5, 2019-03-03:
So I checked the pinout and MCU, both match up with the original bluepill board, so that MCU should work fine. Attached is a zip file containing a STM32flash-based uploader that you can use to manually apply the firmware to your board without compiling with PIO. I'm still stumped, but this should at least let you test your hardware.

After unzipping,
1) Simply connect your board and reset it with the programming pin set like normal.
2) Double-click `UPLOAD.bat`
3) It will ask you for a COM port to target. For example, my MegaBlaster is on COM24, so I'll just type in `COM24`. Make sure COM is in all caps and that there are no spaces.
4) The tool should manually begin to upload the precompiled firmware.

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

[STM32_Upload_Tool.zip](https://github.com/AidanHockey5/STM32_VGM_Player_YM2612_SN76489/files/2923758/stm32flash-0.5-win64.zip)

sparksterz, 2019-03-04:
Aidan...YOU'RE THE GOD DAMN BEST!

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

I forked the repo, and I'm going to see if I can figure out or resolve the issues I have building. I noticed the file size of mine came out to be 61kb versus your provided one which was 59kb...so, something is definitely different. I guess I'll have to try and dig into why ststm32 4.5.0 doesn't work on my box. I'm not sure what you want to do with this bug, feel free to close it if you'd like. If someone else comes along with a similar issue maybe it would be worth reopening then.

AidanHockey5, 2019-03-04:
Yeah!! Awesome, glad to see that your hardware is working and that you were
able to get a successful flash.

This compile bug is weird to me. I'm not entirely satisfied and I wish I
knew what was wrong with your copy of the code. If another person comes
along and has the same issue, I'll be willing to drop in again and lend a
hand. If I make any significant changes to the firmware in the future and
you're still having compile issues, I'll post an updated version of the
precompiled bin.

Alright, so once you're all flashed up, make sure you set the programming
jumper back to 0 so the code stays on the device. Also, it looks like your
PSG switch is set to 0, switch it up to 1 to enable it.

Feel free to drop by any time if you have any more issues!

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

sparksterz, 2019-03-04:
Oh, good to know on the PSG. I didn't have a chance to really listen to much this morning before leaving for work. Because the interactive guide labeled it as "Mute PSG" I assumed 0 was not muted.

sparksterz, 2019-03-08:
Yeah - I tried digging into this for about 3 hours today while being significantly out of my element in terms of dev environment, but anything that I found would either compile and then not run - or I'd find the ever helpful advice of "Point the platform version at the latest in git" followed by "Yep, that worked" which, does not in this case.

I think my problem could be 2 fold. A problem with platform io, and also a problem with the libraries in ststm32...but I'm more just thoroughly confused than anything else right now. I somehow managed to mess up my environment enough that my include paths are entirely bogus and nothing can be found. Maybe I'll try this in an Ubuntu VM and see if I can avoid a headache that way now that I know if I can build it, I still push from Windows if I needed to.

AidanHockey5, 2019-03-08:
So I decided to bring out an old computer of mine that was running Windows 10 x64 and has never had VS Code or PlatformIO installed on it before.
I installed both and cloned the repo. Sure enough, once I opened the project and compiled, I was met with the same wall of `inline` errors.

After playing around with the versions a little, I determined that version `ststm32@~3.8.0` was the highest version that would compile without errors. I uploaded the code to my MegaBlaster and sure enough, it worked like a charm.

Why does my desktop with version 4.5.0 compile fine and this old computer only compile with version 3.8.0? I frankly have no idea. It seems super odd to me.

Anyways, I've pushed the change to 3.8.0 to master. Go ahead and give it a shot and let me know if anything changes!

sparksterz, 2019-03-09:
Yep @AidanHockey5 you've done it again! I can now build and deploy from my machine. Awesome stuff. Now I can actually tinker around a bit with the code and maybe debug some interesting issues I've noticed over the serial port. I'm excited! Hands on learning is my favorite :)

I've learned a few things as well, turns out not all SN76489AN chips are made equal. I put 3 different chips in the socket before finding one that had what I felt the proper pitch and volume levels. Good call on adding sockets for those chips!

AidanHockey5, 2019-03-09:
Great! Glad to hear it's finally working for you. Have fun and happy hacking!

Closed 2019-03-04.

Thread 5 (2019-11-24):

sd mount failed!

agentxxxxxx, 2019-11-24:
oled displays SD MOUNT FAILED!. I had checked all of the sd slot connetions and they are ok. what else should I check?

AidanHockey5, 2019-11-24:
Hello!

An SD card failing to mount could be for a number of reasons.

Have you made sure that the SD card is formatted as FAT32?

Are your VGM files uncompressed? (You can’t use VGZ files, you have to extract the VGM inside of them)

Are the pins inside of your SD socket in good condition?

Did you build this as a breadboard prototype? Some cheap SD card adapters are not designed properly and will never mount correctly.

Have you just recently programmed your board? If so, unplug the board from power, then plug the board back in. SD cards almost never mount after a programming cycle.

agentxxxxxx, 2019-11-25:
thanks for your supports! I had solved it. I wired the sd card pin directly to the stm32 board and it worked. the SD slot might be broken internal.

Thanks for your excellent project! It's wonderful!!

Closed 2019-11-25.

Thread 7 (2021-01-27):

Standalone flasher not working

CornBrown, 2021-01-27:
The error i get is that there are python files missing in c:\users\aiden\....    and wont run    (windows 7 64bit)    Everything is working in win10

AidanHockey5, 2021-01-27:
Hello,

Windows 7 has reached its end of life (EoL) and is therefore unsupported.

I could not recreate your issue on Windows 10. I spooled up a fresh Windows 10 VM with a username that is not "Aidan" and I managed to flash the firmware just fine.
* Make sure the board is receiving 12V and is powered on.
* Make sure that you've got the CH340 drivers installed. You can download them here:
https://cdn.sparkfun.com/assets/learn_tutorials/8/4/4/CH341SER.EXE
* Make sure your left jumper is in the UP position on your blue pill microcontroller board.
https://www.aidanlawrence.com/wp-content/uploads/2021/01/mb_jumper-scaled.jpg
* Make sure you press the RESET button before invoking the programmer.

>Everything is working in win10
Looks like that's the answer. Windows 7 is simply unsupported. You might be able to run the flashing script in Windows 7 via Python. View the README.txt file that's included with the standalone and run Flash.py

Closed 2021-01-27.

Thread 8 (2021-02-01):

BOM needs updating maybe

birdybro, 2021-02-01:
Digikey has changed this component to bulk order only with a minimum quantity of 200.

https://www.digikey.com/en/products/detail/abracon-llc/AIUR-16-330K/5043349

Was about to order and am struggling to find a replacement on there. Perhaps someone who isn't a newbie to electronics can help? Either way, the BOM probably should be updated. :P

EDIT: Also this switch --> https://www.digikey.com/en/products/detail/te-connectivity-alcoswitch-switches/1825115-1/1202217 - is obsoleted by the manufacturer and out of stock on digikey and mouser, and pretty much everywhere else, with no restock estimate (meaning they probably are never producing it again). I tried finding a suitable replacement, was kinda struggling with that.

Closed 2021-04-01.

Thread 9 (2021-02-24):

update problem

6502bender, 2021-02-24:
Hello
After upgrading mega blaster to v3.0, there were problems with SN76489. PSG began to sound terrible, extraneous sounds appear and the frequency seems to be floating
Here is a link to a video for an example. https://youtu.be/bkRAT_hYAm4
There is no such problem in version 2.0.
YM on the contrary, began to sound much better.
thank.

AidanHockey5, 2021-02-25:
Your issue has been replicated. There is something wrong with the way that I'm writing to the PSG. I'll see if I can find a solution.

AidanHockey5, 2021-02-25:
Unable to verify on the official Mega Blaster board. The PSG works just fine. I previously thought there might have been an issue, but I noticed that my PSG MUTE switch was set.

Sadly, since your board is hand-made, I won't be able to help you much. I would try and verify your hardware against the original schematic. Make sure the PSG's WE pin is connected to pin PB5.

6502bender, 2021-02-25:
the fact is that if I upload the firmware v2.0, then PSG sounds as expected.

2021-02-25 20:07 GMT+03:00, Aidan Lawrence <notifications@github.com>:
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

jareklupinski, 2021-02-25:
that's a wild board!
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
rly the only diff in the sn-specific code is the amount of microseconds btwn writes, maybe on a hand-spun board this 3uS difference is the factor?
I'm finding the PSG loves taking almost the entire sample to clock its data bus :(

6502bender, 2021-02-25:
Thank you, so I will dig towards SN76489, but that will be later.

Now I started another experiment, it might be interesting.

https://youtu.be/YdA0xXXmrXM

The bottom line is to use the YMF276-M synthesizer

The YMF276-M was used in FM Towns II computers, and is kind of a lower power version of the YM3438.

The main feature of this chip (for me) is that it requires an external DAC (using the I2S interface). Therefore, the DAC with a preamplifier can be maximally isolated from the digital part, thereby seriously reducing digital noise, pickup, etc. in the sound.

The DAC used the BU9480F.

Next, I want to screw this chip to my console.

Closed 2021-02-25.

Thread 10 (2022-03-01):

Some VGMs are freezing.

VectorFever, 2022-03-01:
Everything works from VGMRips except some Contra tracks. But every track from DefleMask doesn't work at all. Even if it doesn't contain any samples and file sizes are small. Player just freezes. Previously i made ym2151 player(not your player, by Hiromasa Tanaka) and it works with all VGMs perfect. Why is it happening? There is so much fan made tracks and covers that just better than originals. Thank you for support. 😃

AidanHockey5, 2022-03-01:
Hello,

So, YM2151 tracks are very simple to play as they’re generally FM-only. PCM
samples are delegated to other chips. YM2612s feature on-board DACs, so the
PCM samples are expected in almost all soundtracks, thus quite an excessive
amount of RAM is required to handle all that extra sample data.

This player was an earlier version of my Mega Blaster design that featured
an STM32 microcontroller that didn’t have very much RAM, so PCM sample size
was limited. Furthermore, advanced functions like DAC Streams were never
implemented due to the limitations of the platform.

Therefore, VGM tracks that have very large PCM sample storage requirements
are skipped automatically by the player and any tracks that utilize DAC
streams (often utilized by home brew composers), will cause the player to
error out.

All of these issues have been fixed in my latest revision of the Mega
Blaster project found here:
https://github.com/AidanHockey5/MegaBlaster2

This upgraded version of the project has a far more capable
microcontroller, lots more internal RAM, and even more external RAM. It’s
better in just about every way and supports DAC streams and tracks with
demanding PCM requirements.

The original Mega Blaster project (this repository), is no longer updated
as it has been superseded by its successor. I apologize for any
inconvenience, but the advanced features of the VGM specification really
did require much more capable hardware, so a board revision was necessary.

On Mon, Feb 28, 2022 at 5:27 PM VectorFever ***@***.***>
wrote:

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

VectorFever, 2022-03-01:
I mean... It can easily play Streets of Rage 2 intro that is 1705kb(or something around it). But can't play 2kb test that i made in DefleMask which contains only four notes and no samples at all. Just freezes and it's all.

VectorFever, 2022-03-01:
I think I know what to do. I can run vgm player in sega emulator and then rip off vgm from emulator while it's playing. I tested this player before with emulator and on real mega drive 2 with flash cart.

VectorFever, 2022-03-01:
Maybe DefleMask codes tracks in VGM different way. Like VGM versions and others

AidanHockey5, 2022-03-01:
If there are no samples, then deflemask may be exporting compressed “VGZ”
files, which are definitely not supported on the old Mega Blaster.
You may be able to use 7zip to extract the standard VGM file from the VGZ
file if it is indeed compressed.

On Mon, Feb 28, 2022 at 6:21 PM VectorFever ***@***.***>
wrote:

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

VectorFever, 2022-03-01:
No. It's VGM. There is nothing to unzip. And ym2151 player i made can play only vgm too. But i just export vgm,drop on sd and it's working. idk what happening 🤨

VectorFever, 2022-03-01:
Jesus... It worked! Even if file size is 9mb

Closed 2022-03-01.

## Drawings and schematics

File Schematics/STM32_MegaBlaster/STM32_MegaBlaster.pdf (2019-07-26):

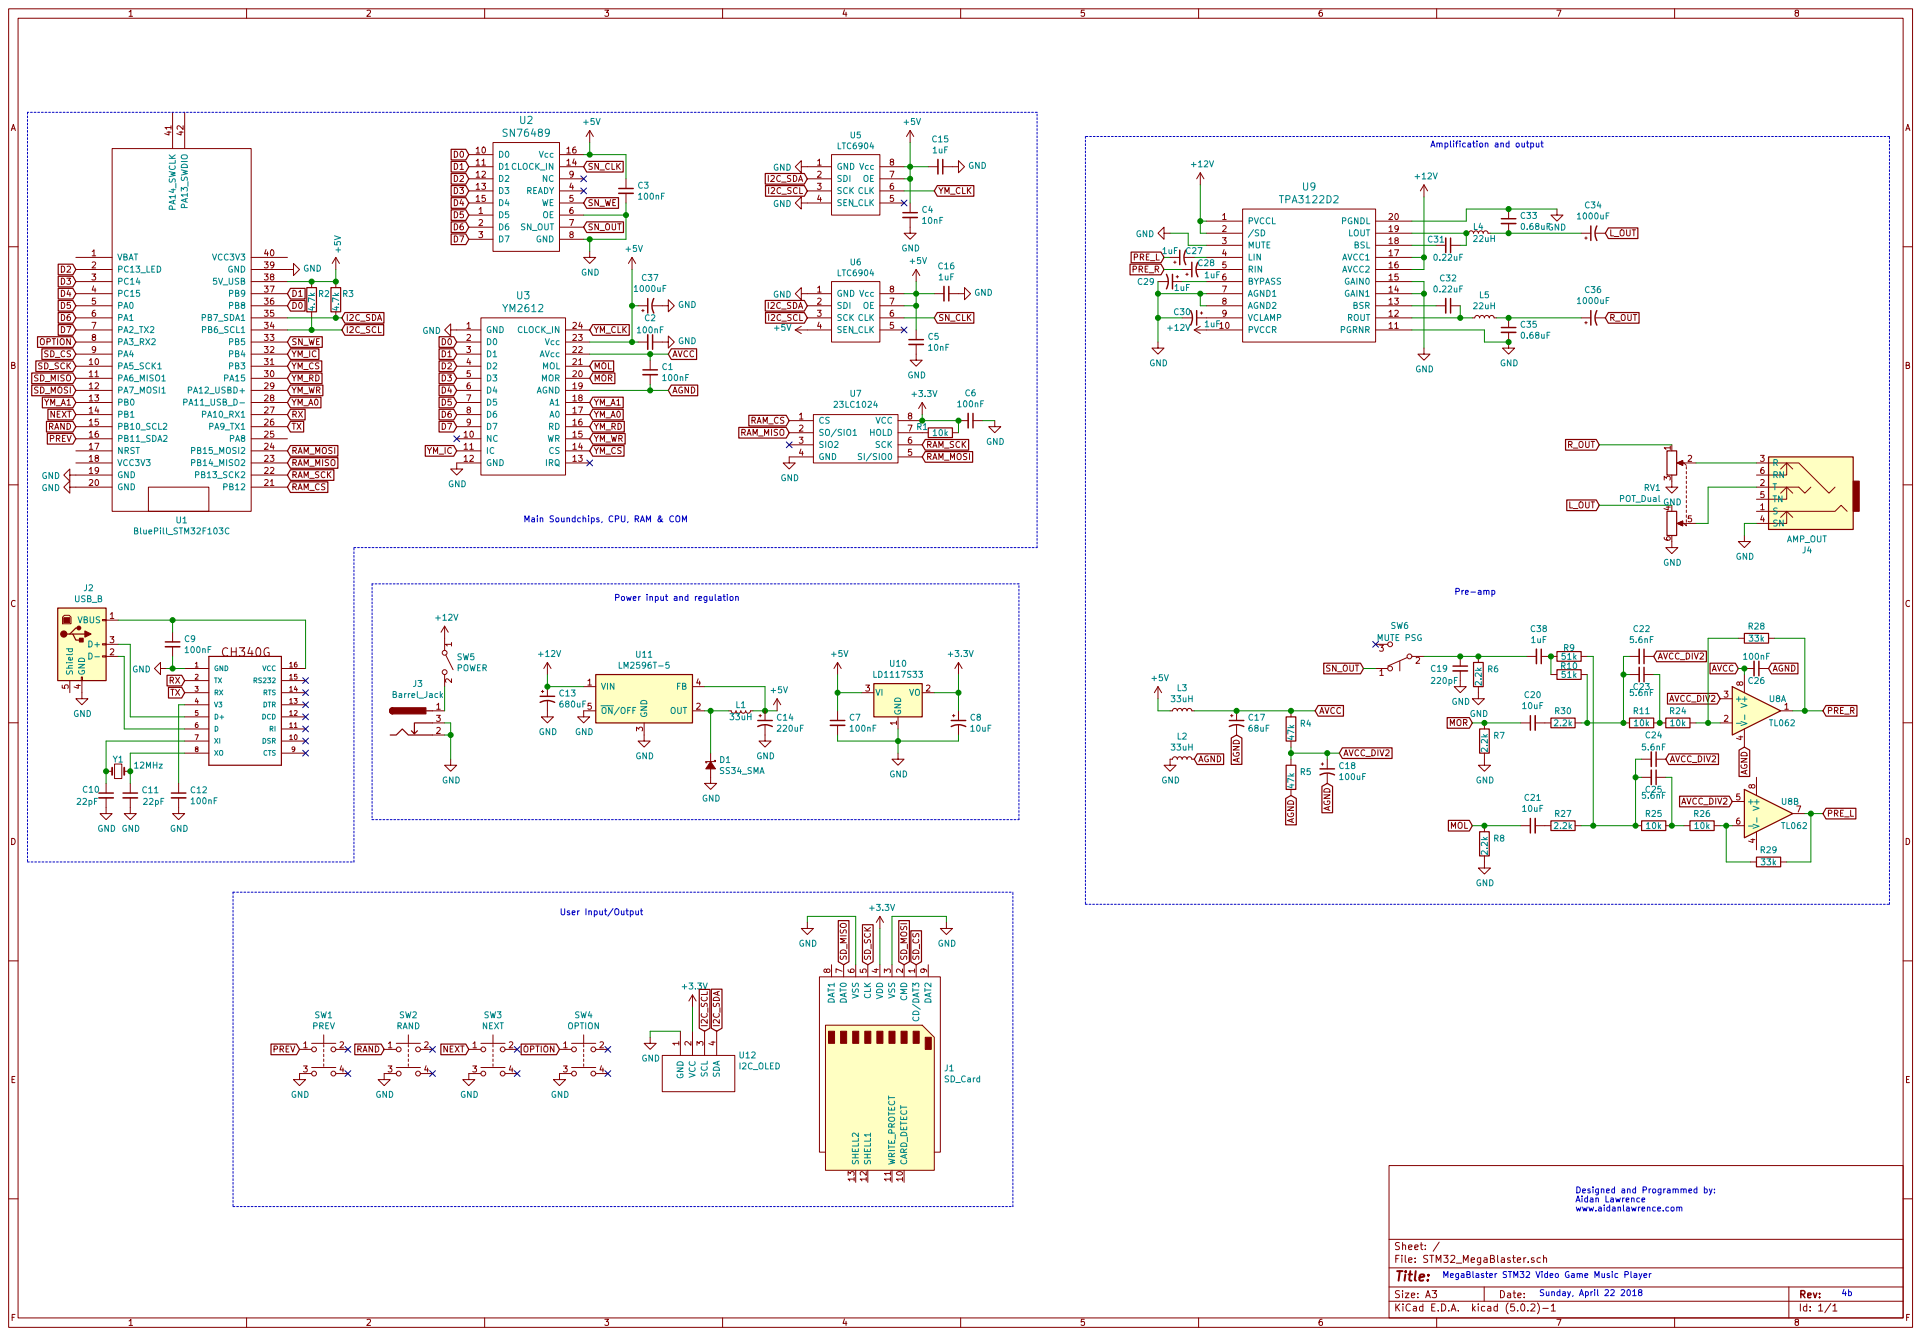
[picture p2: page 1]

+3.3V Main Soundchips, CPU, RAM & COM

Power input and regulation

Designed and Programmed by: Aidan Lawrence www.aidanlawrence.com

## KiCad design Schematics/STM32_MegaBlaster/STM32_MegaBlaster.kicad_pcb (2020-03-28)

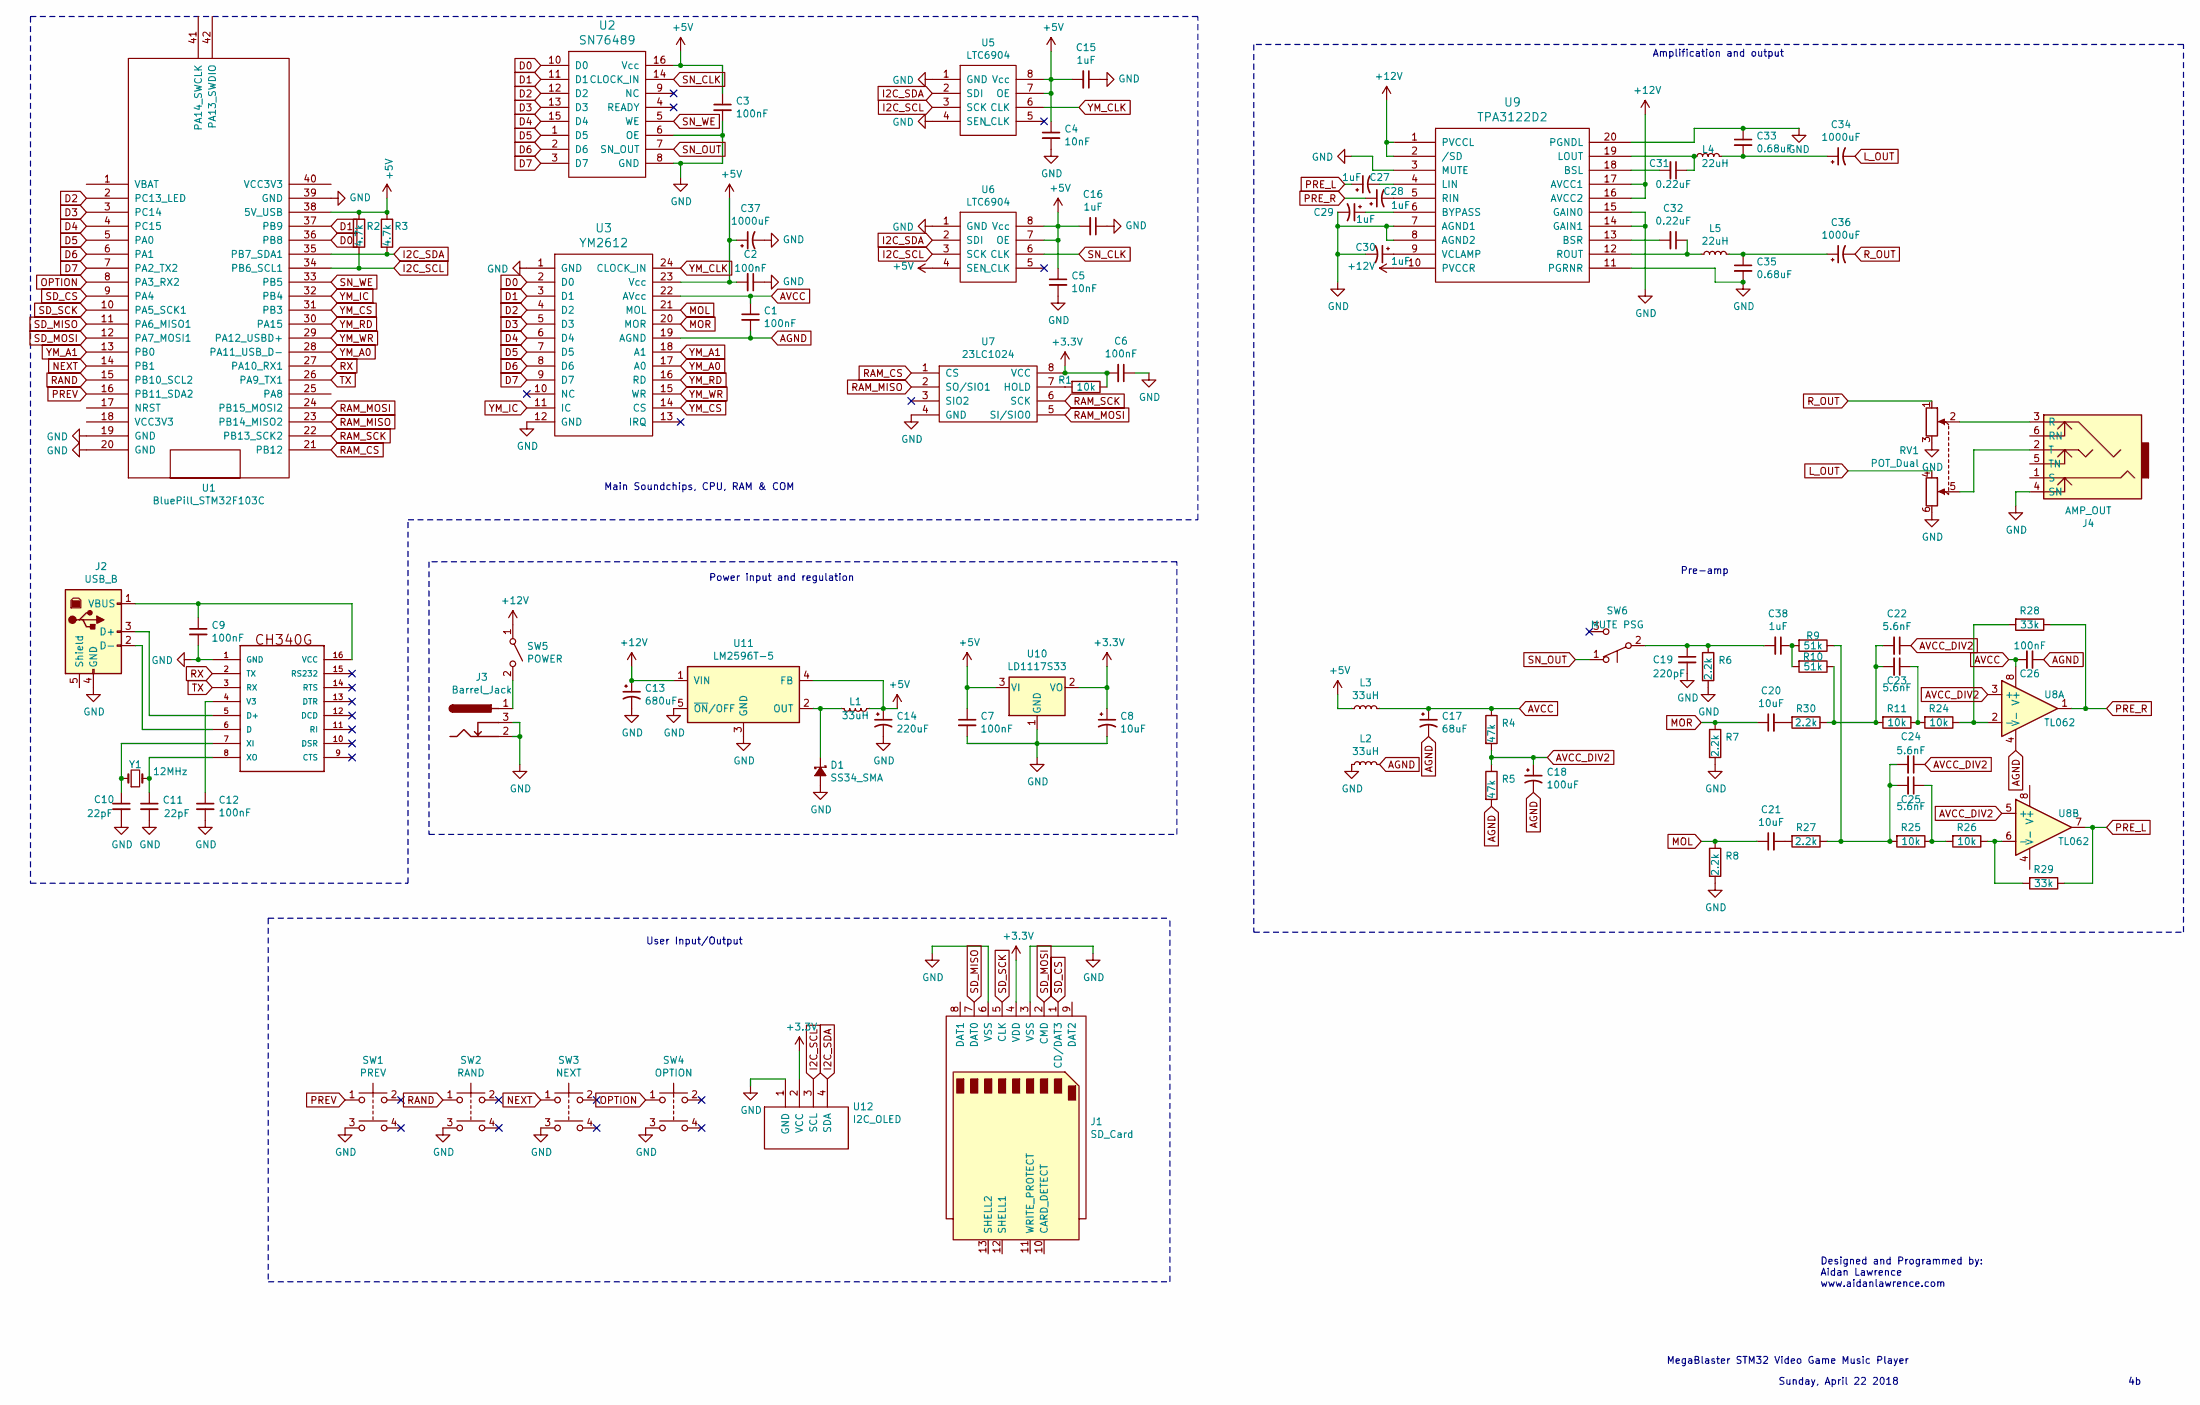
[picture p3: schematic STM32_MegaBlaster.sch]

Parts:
C1, C2, C6, C7, C9, C12, C26: 100nF; C_Disc_D3.0mm_W1.6mm_P2.50mm
C3: 100nF; C_Axial_L22.0mm_D10.5mm_P27.50mm_Horizontal
C4, C5: 10nF; C_Disc_D3.0mm_W1.6mm_P2.50mm
C8: 10uF; CP_Radial_D4.0mm_P1.50mm
C10, C11: 22pF; C_Disc_D3.0mm_W1.6mm_P2.50mm
C13: 680uF; CP_Radial_D10.0mm_P5.00mm
C14: 220uF; CP_Radial_D6.3mm_P2.50mm
C15, C16, C38: 1uF; C_Disc_D4.7mm_W2.5mm_P5.00mm
C17: 68uF; CP_Radial_D6.3mm_P2.50mm
C18: 100uF; CP_Radial_D5.0mm_P2.00mm
C19: 220pF; C_Disc_D4.7mm_W2.5mm_P5.00mm
C20, C21: 10uF; C_Disc_D4.7mm_W2.5mm_P5.00mm
C22, C23, C24, C25: 5.6nF; C_Disc_D4.7mm_W2.5mm_P5.00mm
C27, C28, C29, C30: 1uF; CP_Radial_D4.0mm_P1.50mm
C31, C32: 0.22uF; C_Disc_D4.7mm_W2.5mm_P5.00mm
C33: 0.68uF; C_Disc_D3.0mm_W1.6mm_P2.50mm
C34, C36, C37: 1000uF; CP_Radial_D8.0mm_P2.50mm
C35: 0.68uF; CP_Radial_D6.3mm_P2.50mm
D1: SS34_SMA; D_SOD-123F
J1: SD_Card; SD_TE_2041021
J2: USB_B
J3: Barrel_Jack; BARREL_JACK
J4: AMP_OUT; PJ320E_3.5mm_Jack
L1, L2, L3: 33uH; L_Radial_D7.0mm_P3.00mm
L4, L5: 22uH; L_Radial_D8.7mm_P5.00mm_Fastron_07HCP
R1, R11, R24, R25, R26: 10k; R_Axial_DIN0207_L6.3mm_D2.5mm_P7.62mm_Horizontal
R2, R3: 4.7k; R_Axial_DIN0207_L6.3mm_D2.5mm_P7.62mm_Horizontal
R4, R5: 47k; R_Axial_DIN0207_L6.3mm_D2.5mm_P7.62mm_Horizontal
R6, R7, R8, R27, R30: 2.2k; R_Axial_DIN0207_L6.3mm_D2.5mm_P7.62mm_Horizontal
R9, R10: 51k; R_Axial_DIN0207_L6.3mm_D2.5mm_P7.62mm_Horizontal
R28, R29: 33k; R_Axial_DIN0207_L6.3mm_D2.5mm_P7.62mm_Horizontal
RV1: POT_Dual; Potentiometer_Alps_RK163_Double_Vertical
SW1: PREV; SW_TH_Tactile_Omron_B3F-10xx
SW2: RAND; SW_TH_Tactile_Omron_B3F-10xx
SW3: NEXT; SW_TH_Tactile_Omron_B3F-10xx
SW4: OPTION; SW_TH_Tactile_Omron_B3F-10xx
SW5: POWER; 1825115-1
SW6: MUTE PSG; 1825115-1
U1: BluePill_STM32F103C
U2: SN76489; DIP-16_W7.62mm
U3: YM2612; DIP-24_W15.24mm
U4: CH340G; SOIC16
U5, U6: LTC6904; MSOP-8_3x3mm_Pitch0.65mm
U7: 23LC1024; DIP-8_W7.62mm
U8: TL062; DIP-8_W7.62mm
U9: TPA3122D2; DIP-20_W7.62mm
U10: LD1117S33; SOT-223-3_TabPin2
U11: LM2596T-5; TO170P1435X465-6N
U12: I2C_OLED; 1_3_Inch_I2C_OLED
Y1: 12MHz; Crystal_HC49-U_Vertical

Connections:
+3V3: C6.2, C8.1, J1.4 (VDD), R1.1, U7.8 (VCC), U10.2 (VO), U12.2 (VCC)
+5V: C2.2, C3.1, C4.1, C5.1, C7.1, C14.1, C15.2, C16.2, C37.1, L1.1, L3.1, R2.1, R3.1, U1.38 (5V_USB), U2.16 (Vcc), U3.23 (Vcc), U5.7 (OE), U5.8 (Vcc), U6.4 (SEN), U6.7 (OE), U6.8 (Vcc), U10.3 (VI), U11.4 (FB)
+12V: C13.1, SW5.1 (A), U9.1 (PVCCL), U9.2 (/SD), U9.10 (PVCCR), U9.16 (AVCC2), U9.17 (AVCC1), U11.1 (VIN)
AGND: C1.2, C17.2, C18.2, C26.1, L2.2, R5.2, U3.19 (AGND), U8.4 (V-)
AVCC: C1.1, C17.1, C26.2, L3.2, R4.1, U3.22 (AVcc), U8.8 (V+)
AVCC_DIV2: C18.1, C22.1, C24.1, R4.2, R5.1, U8.3 (+), U8.5 (+)
D0: U1.36 (PB8), U2.10 (D0), U3.2 (D0)
D1: U1.37 (PB9), U2.11 (D1), U3.3 (D1)
D2: U1.2 (PC13_LED), U2.12 (D2), U3.4 (D2)
D3: U1.3 (PC14), U2.13 (D3), U3.5 (D3)
D4: U1.4 (PC15), U2.15 (D4), U3.6 (D4)
D5: U1.5 (PA0), U2.1 (D5), U3.7 (D5)
D6: U1.6 (PA1), U2.2 (D6), U3.8 (D6)
D7: U1.7 (PA2_TX2), U2.3 (D7), U3.9 (D7)
GND: C2.1, C3.2, C4.2, C5.2, C6.1, C7.2, C8.2, C9.2, C10.2, C11.2, C12.2, C13.2, C14.2, C15.1, C16.1, C19.2, C29.2, C30.2, C33.1, C35.2, C37.2, D1.2 (A), J1.3 (VSS), J1.6 (VSS), J2.4 (GND), J3.2, J3.3, J4.3 (R), J4.4 (SN), L2.1, R6.2, R7.2, R8.2, RV1.2, RV1.3, RV1.6, SW1.3, SW2.3, SW3.3, SW4.3, U1.19 (GND), U1.20 (GND), U1.39 (GND), U2.6 (OE), U2.8 (GND), U3.1 (GND), U3.12 (GND), U4.1 (GND), U5.1 (GND), U5.4 (SEN), U6.1 (GND), U7.4 (GND), U9.3 (MUTE), U9.7 (AGND1), U9.8 (AGND2), U9.11 (PGRNR), U9.14 (GAIN1), U9.15 (GAIN0), U9.20 (PGNDL), U10.1 (GND), U11.3 (GND), U11.5 (~ON~/OFF), U11.6, U12.1 (GND); also elsewhere on the board
I2C_SCL: R2.2, U1.34 (PB6_SCL1), U5.3 (SCK), U6.3 (SCK), U12.3 (SCL)
I2C_SDA: R3.2, U1.35 (PB7_SDA1), U5.2 (SDI), U6.2 (SDI), U12.4 (SDA)
L_OUT: C34.2, RV1.4; also elsewhere on the board
MOL: C21.1, R8.1, U3.21 (MOL)
MOR: C20.1, R7.1, U3.20 (MOR)
NEXT: SW3.1, U1.14 (PB1); also elsewhere on the board
unnamed: C9.1, J2.1 (VBUS), U4.16 (VCC)
unnamed: C10.1, U4.7 (XI), Y1.1
unnamed: C11.1, U4.8 (XO), Y1.2
unnamed: C12.1, U4.4 (V3)
unnamed: C19.1, C38.2, R6.1, SW6.2 (B)
unnamed: C20.2, R30.2
unnamed: C21.2, R27.2
unnamed: C22.2, C23.2, R10.1, R11.2, R30.1
unnamed: C23.1, R11.1, R24.2
unnamed: C24.2, C25.2, R9.1, R25.2, R27.1
unnamed: C25.1, R25.1, R26.2
unnamed: C27.2, U9.4 (LIN)
unnamed: C28.2, U9.5 (RIN)
unnamed: C29.1, U9.6 (BYPASS)
unnamed: C30.1, U9.9 (VCLAMP)
unnamed: C31.1, L4.1, U9.19 (LOUT)
unnamed: C31.2, U9.18 (BSL)
unnamed: C32.1, L5.1, U9.12 (ROUT)
unnamed: C32.2, U9.13 (BSR)
unnamed: C33.2, C34.1, L4.2
unnamed: C35.1, C36.1, L5.2
unnamed: C38.1, R9.2, R10.2
unnamed: D1.1 (K), L1.2, U11.2 (OUT)
unnamed: J2.2 (D-), U4.6 (D)
unnamed: J2.3 (D+), U4.5 (D+)
unnamed: J3.1, SW5.2 (B)
unnamed 53: J4.1 (S); also elsewhere on the board
unnamed 54: J4.2 (T), RV1.5; also elsewhere on the board
unnamed: R1.2, U7.7 (HOLD)
unnamed: R24.1, R28.2, U8.2 (-)
unnamed: R26.1, R29.2, U8.6 (-)
OPTION: SW4.1, U1.8 (PA3_RX2); also elsewhere on the board
PREV: SW1.1, U1.16 (PB11_SDA2); also elsewhere on the board
PRE_L: C27.1, R29.1, U8.7
PRE_R: C28.1, R28.1, U8.1
RAM_CS: U1.21 (PB12), U7.1 (CS)
RAM_MISO: U1.23 (PB14_MISO2), U7.2 (SO/SIO1)
RAM_MOSI: U1.24 (PB15_MOSI2), U7.5 (SI/SIO0)
RAM_SCK: U1.22 (PB13_SCK2), U7.6 (SCK)
RAND: SW2.1, U1.15 (PB10_SCL2); also elsewhere on the board
RX: U1.27 (PA10_RX1), U4.2 (TX)
R_OUT: C36.2, RV1.1; also elsewhere on the board
SD_CS: J1.1 (CD/DAT3), U1.9 (PA4)
SD_MISO: J1.7 (DAT0), U1.11 (PA6_MISO1)
SD_MOSI: J1.2 (CMD), U1.12 (PA7_MOSI1)
SD_SCK: J1.5 (CLK), U1.10 (PA5_SCK1)
SN_CLK: U2.14 (CLOCK_IN), U6.6 (CLK)
SN_OUT: SW6.1 (A), U2.7 (SN_OUT)
SN_WE: U1.33 (PB5), U2.5 (WE)
TX: U1.26 (PA9_TX1), U4.3 (RX)
YM_A0: U1.28 (PA11_USB_D-), U3.17 (A0)
YM_A1: U1.13 (PB0), U3.18 (A1)
YM_CLK: U3.24 (CLOCK_IN), U5.6 (CLK)
YM_CS: U1.31 (PB3), U3.14 (CS)
YM_IC: U1.32 (PB4), U3.11 (IC)
YM_RD: U1.30 (PA15), U3.16 (RD)
YM_WR: U1.29 (PA12_USBD+), U3.15 (WR)

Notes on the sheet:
MegaBlaster STM32 Video Game Music Player
Sunday, April 22 2018
Designed and Programmed by: Aidan Lawrence www.aidanlawrence.com
Main Soundchips, CPU, RAM & COM
Power input and regulation
User Input/Output
Amplification and output
Pre-amp

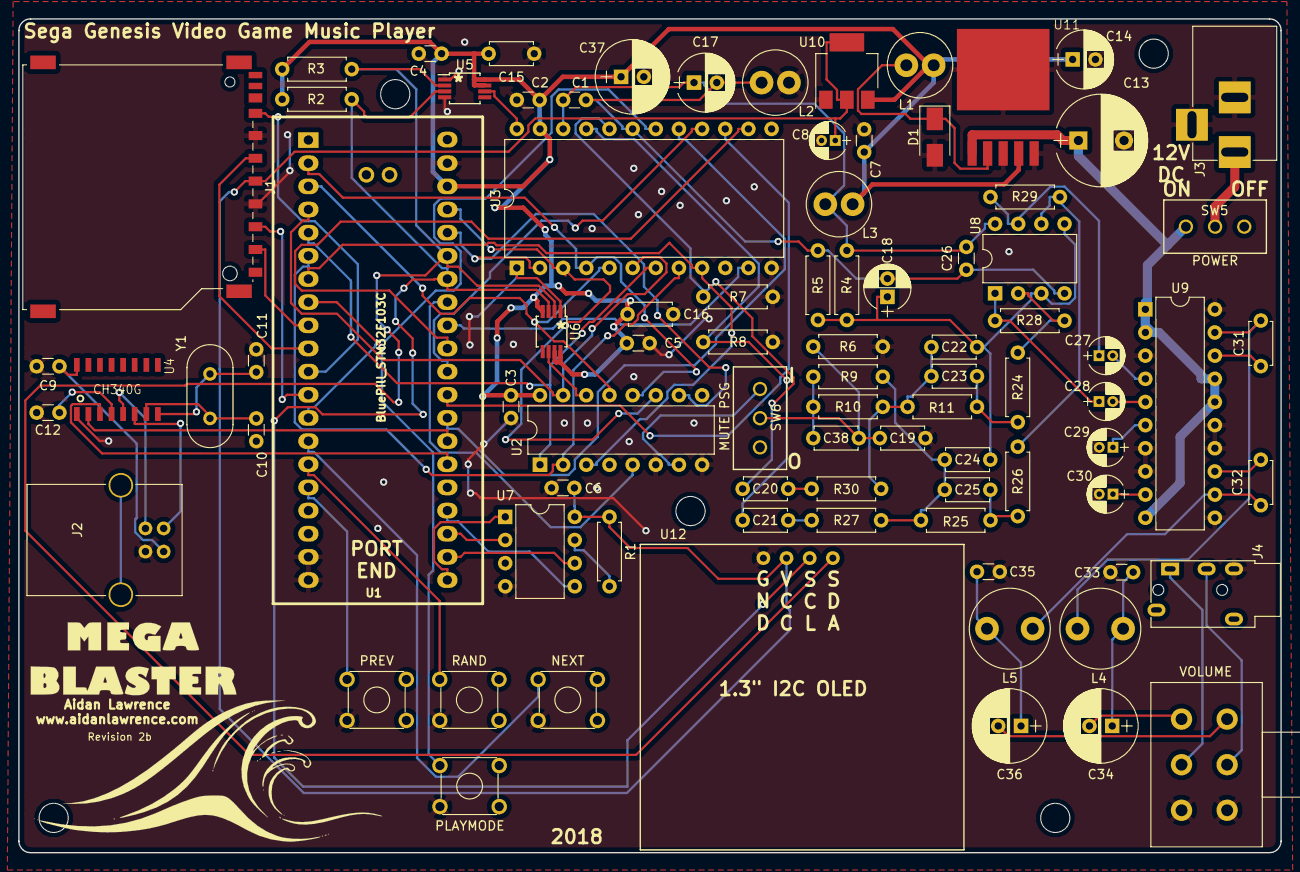
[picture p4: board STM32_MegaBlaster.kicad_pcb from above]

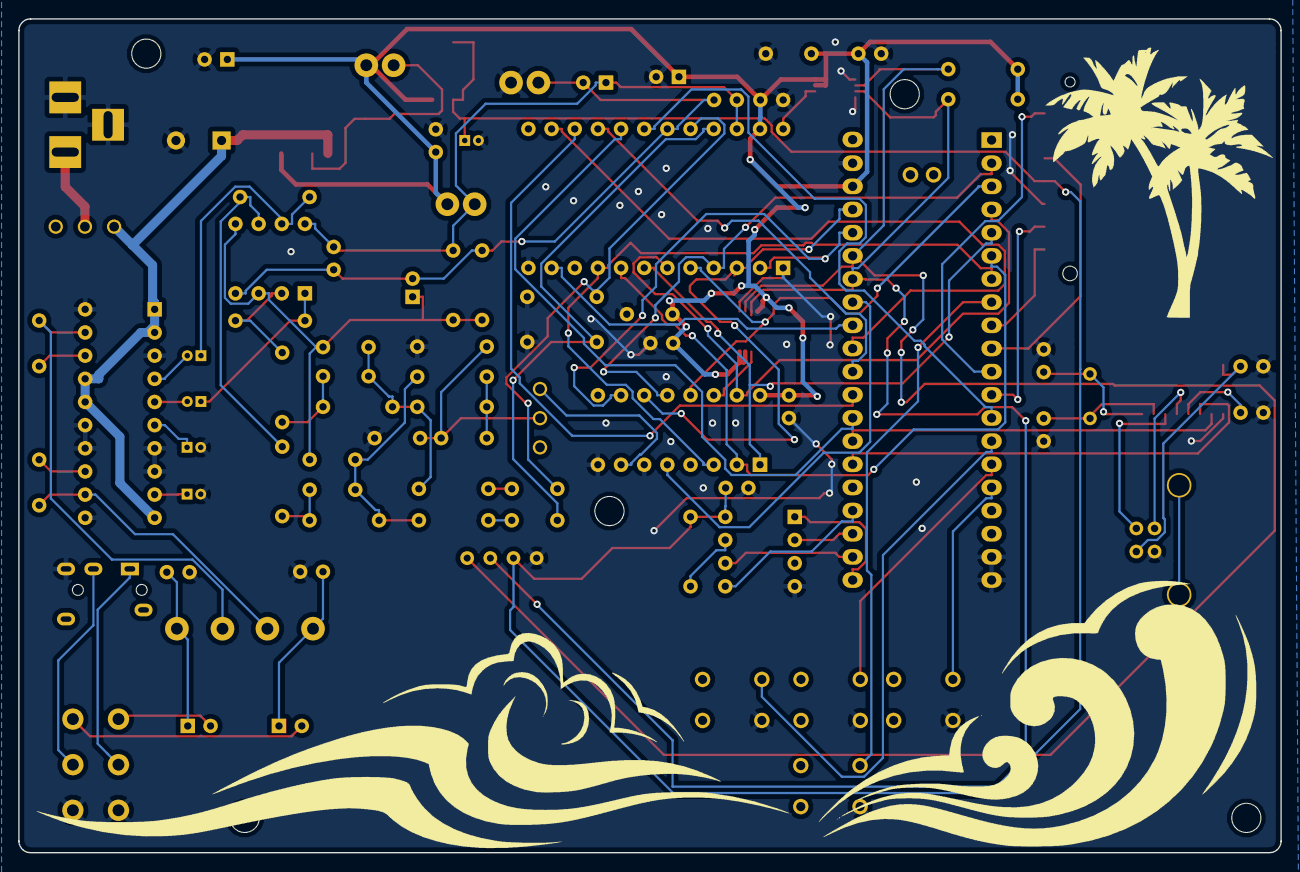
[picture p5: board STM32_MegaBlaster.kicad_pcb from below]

Board: 2 copper layers, 138.4 x 91.4 mm, 95 parts (2 on the bottom side), 78 nets.

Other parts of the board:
G1: LOGO; wave1
G2: LOGO; mega_blaster_logo
G3: LOGO; wave2
G4: LOGO; trees
H1, H1#2, H1#3, H1#4, H1#5: MountingHole_3.2mm_M3
NEXT: NEXT; SW_TH_Tactile_Omron_B3F-10xx
PLAYMODE: OPTION; SW_TH_Tactile_Omron_B3F-10xx
PREV: PREV; SW_TH_Tactile_Omron_B3F-10xx
RAND: RAND; SW_TH_Tactile_Omron_B3F-10xx
VOLUME: POT_Dual; Potentiometer_Alps_RK163_Double_Vertical(SWAP)

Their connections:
GND: NEXT.3, PLAYMODE.3, PREV.3, RAND.3, VOLUME.3, VOLUME.6; also elsewhere on the board
L_OUT: VOLUME.4; also elsewhere on the board
NEXT: NEXT.1; also elsewhere on the board
unnamed 53: VOLUME.5; also elsewhere on the board
unnamed 54: VOLUME.2; also elsewhere on the board
OPTION: PLAYMODE.1; also elsewhere on the board
PREV: PREV.1; also elsewhere on the board
RAND: RAND.1; also elsewhere on the board
R_OUT: VOLUME.1; also elsewhere on the board

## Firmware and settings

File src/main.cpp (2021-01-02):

#include <Arduino.h>
#include <SPI.h>
#include <Wire.h>
#include "SdFat.h"
#include "U8g2lib.h" //Run this command in the terminal below if PIO asks for a dependancy: pio lib install "U8g2"
#include "LTC6904.h"
#include "YM2612.h"
#include "SN76489.h"
#include "logo.h"
#include "SpinSleep.h"
#include "SerialUtils.h"

#include "VGMEngine.h"

//Debug variables
#define DEBUG true //Set this to true for a detailed printout of the header data & any errored command bytes
#define DEBUG_LED PA8
bool commandFailed = false;
uint8_t failedCmd = 0x00;

//Structs
enum FileStrategy {FIRST_START, NEXT, PREV, RND, REQUEST};
enum PlayMode {LOOP, PAUSE, SHUFFLE, IN_ORDER};

//Prototypes
void setup();
void loop();
void handleSerialIn();
void tick();
void setISR();
void pauseISR();
void removeMeta();
void prebufferLoop();
void injectPrebuffer();
void fillBuffer();
bool topUpBuffer(); 
void clearBuffers();
void handleButtons();
void prepareChips();
void readGD3();
void drawOLEDTrackInfo();
bool startTrack(FileStrategy fileStrategy, String request = "");
bool vgmVerify();
uint8_t VgmCommandLength(uint8_t Command);
uint8_t readBuffer();
uint16_t readBuffer16();
uint32_t readBuffer32();
uint32_t readSD32();
uint16_t parseVGM();


Bus bus(PB8, PB9, PC13, PC14, PC15, PA0, PA1, PA2);

YM2612 opn(&bus, PB3, NULL, PA12, PA11, PB0, PB4);
SN76489 sn(&bus, PB5);

//OLED
U8G2_SH1106_128X64_NONAME_F_HW_I2C oled(U8G2_R0);
//U8G2_SH1106_128X64_NONAME_F_HW_I2C oled(U8G2_R0);
//U8G2_SSD1306_128X64_NONAME_F_HW_I2C oled(U8G2_R0);
bool isOledOn = true;

//Buttons
const int prev_btn = PB11;
const int rand_btn = PB10;
const int next_btn = PB1;
const int option_btn = PA3;

//SD & File Streaming
SdFat SD;
File file;
#define MAX_FILE_NAME_SIZE 128
char fileName[MAX_FILE_NAME_SIZE];
uint32_t numberOfFiles = 0;
uint32_t currentFileNumber = 0;

//Counters
uint32_t bufferPos = 0;
uint32_t cmdPos = 0;
uint16_t waitSamples = 0;
uint32_t pcmBufferPosition = 0;

//VGM Variables
uint16_t loopCount = 0;
uint8_t maxLoops = 3;
bool fetching = false;
volatile bool ready = false;
bool samplePlaying = false;
PlayMode playMode = SHUFFLE;
bool doParse = false;

void setup()
{
  //DEBUG
  pinMode(DEBUG_LED, OUTPUT);
  digitalWrite(DEBUG_LED, LOW);
  disableDebugPorts();
  resetSleepSpin();

  //Buttons
  pinMode(prev_btn, INPUT_PULLUP);
  pinMode(rand_btn, INPUT_PULLUP);
  pinMode(next_btn, INPUT_PULLUP);
  pinMode(option_btn, INPUT_PULLUP);

  //COM
  Wire.begin();
  SPI.begin();
  Serial.begin(115200);

  // //Clocks
  // ltcOPN.SetFrequency(7670454); //PAL 7600489 //NTSC 7670453
  // ltcSN.SetFrequency(3579545);  //PAL 3546894 //NTSC 3579545 

  //Set Chips
  VGMEngine.ym2612 = &opn;
  VGMEngine.sn76489 = &sn;

  //OLED
  oled.begin();
  oled.setFont(u8g2_font_fub11_tf);
  oled.drawXBM(0,0, logo_width, logo_height, logo);
  oled.sendBuffer();
  delay(3000);
  oled.clearDisplay();

  //SD
  if(!SD.begin(PA4, SD_SCK_HZ(F_CPU/2)))
  {
    Serial.println("SD Mount Failed!");
    oled.clearBuffer();
    oled.drawStr(0,16,"SD Mount");
    oled.drawStr(0,32,"failed!");
    oled.sendBuffer();
    while(true){Serial.println("SD MOUNT FAILED"); delay(1000);}
  }

  Serial.flush();

  //Prepare files
  removeMeta();

  File countFile;
  while ( countFile.openNext( SD.vwd(), O_READ ))
  {
    countFile.close();
    numberOfFiles++;
  }

  countFile.close();
  SD.vwd()->rewind();

  //Begin
  startTrack(FIRST_START);
}

void removeMeta() //Remove useless meta files
{
  File tmpFile;
  while ( tmpFile.openNext( SD.vwd(), O_READ ))
  {
    memset(fileName, 0x00, MAX_FILE_NAME_SIZE);
    tmpFile.getName(fileName, MAX_FILE_NAME_SIZE);
    if(fileName[0]=='.')
    {
      if(!SD.remove(fileName))
      if(!tmpFile.rmRfStar())
      {
        Serial.print("FAILED TO DELETE META FILE"); Serial.println(fileName);
      }
    }
    if(String(fileName) == "System Volume Information")
    {
      if(!tmpFile.rmRfStar())
        Serial.println("FAILED TO REMOVE SVI");
    }
    tmpFile.close();
  }
  tmpFile.close();
  SD.vwd()->rewind();
}

void setISR()
{
  Timer2.pause();
  Timer2.setPrescaleFactor(1);
  Timer2.setOverflow(1633);
  Timer2.setChannel1Mode(TIMER_OUTPUT_COMPARE);
  Timer2.attachInterrupt(TIMER_CH2, tick);
  Timer2.refresh();
  Timer2.resume();   
}

void pauseISR()
{
  Timer2.pause();
}

void drawOLEDTrackInfo()
{
  ready = false;
  if(isOledOn)
  {
    oled.setPowerSave(0);
    oled.clearDisplay();
    oled.setFont(u8g2_font_helvR08_te);
    oled.sendBuffer();
    oled.drawStr(0,10, widetochar(VGMEngine.gd3.enTrackName));
    oled.drawStr(0,20, widetochar(VGMEngine.gd3.enGameName));
    oled.drawStr(0,30, widetochar(VGMEngine.gd3.releaseDate));
    oled.drawStr(0,40, widetochar(VGMEngine.gd3.enSystemName));
    String fileNumberData = "File: " + String(currentFileNumber+1) + "/" + String(numberOfFiles);
    char* cstr;
    cstr = &fileNumberData[0u];
    oled.drawStr(0,50, cstr);
    String playmodeStatus;
    if(playMode == LOOP)
      playmodeStatus = "LOOP";
    else if(playMode == SHUFFLE)
      playmodeStatus = "SHUFFLE";
    else
      playmodeStatus = "IN ORDER";
    cstr = &playmodeStatus[0u];
    oled.drawStr(0, 60, cstr);
    oled.sendBuffer();
  }
  else
  {
    oled.clearDisplay();
    oled.setPowerSave(1);
    oled.sendBuffer();
  }
  ready = true;
}

//Mount file and prepare for playback. Returns true if file is found.
bool startTrack(FileStrategy fileStrategy, String request)
{
  pauseISR();
  ready = false;
  File nextFile;
  memset(fileName, 0x00, MAX_FILE_NAME_SIZE);

  switch(fileStrategy)
  {
    case FIRST_START:
    {
      nextFile.openNext(SD.vwd(), O_READ);
      nextFile.getName(fileName, MAX_FILE_NAME_SIZE);
      nextFile.close();
      currentFileNumber = 0;
    }
    break;
    case NEXT:
    {
      if(currentFileNumber+1 >= numberOfFiles)
      {
          SD.vwd()->rewind();
          currentFileNumber = 0;
      }
      else
          currentFileNumber++;
      nextFile.openNext(SD.vwd(), O_READ);
      nextFile.getName(fileName, MAX_FILE_NAME_SIZE);
      nextFile.close();
    }
    break;
    case PREV:
    {
      if(currentFileNumber != 0)
      {
        currentFileNumber--;
        SD.vwd()->rewind();
        for(uint32_t i = 0; i<=currentFileNumber; i++)
        {
          nextFile.close();
          nextFile.openNext(SD.vwd(), O_READ);
        }
        nextFile.getName(fileName, MAX_FILE_NAME_SIZE);
        nextFile.close();
      }
      else
      {
        currentFileNumber = numberOfFiles-1;
        SD.vwd()->rewind();
        for(uint32_t i = 0; i<=currentFileNumber; i++)
        {
          nextFile.close();
          nextFile.openNext(SD.vwd(), O_READ);
        }
        nextFile.getName(fileName, MAX_FILE_NAME_SIZE);
        nextFile.close();
      }
    }
    break;
    case RND:
    {
      randomSeed(micros());
      uint32_t randomFile = currentFileNumber;
      if(numberOfFiles > 1)
      {
        while(randomFile == currentFileNumber)
          randomFile = random(numberOfFiles-1);
      }
      currentFileNumber = randomFile;
      SD.vwd()->rewind();
      nextFile.openNext(SD.vwd(), O_READ);
      {
        for(uint32_t i = 0; i<randomFile; i++)
        {
          nextFile.close();
          nextFile.openNext(SD.vwd(), O_READ);
        }
      }
      nextFile.getName(fileName, MAX_FILE_NAME_SIZE);
      nextFile.close();
    }
    break;
    case REQUEST:
    {
      request.trim();
      char *cstr = &request[0u]; //Convert to C-string
      if(SD.exists(cstr))
      {
        file.close();
        strcpy(fileName, cstr);
        Serial.println("File found!");
      }
      else
      {
        Serial.println("ERROR: File not found! Continuing with current song.");
        goto fail;
      }
    }
    break;
  }

  if(SD.exists(fileName))
    file.close();
  file = SD.open(fileName, FILE_READ);
  if(!file)
  {
    Serial.println("Failed to read file");
    goto fail;
  }
  else
  {
    delay(100);
    if(VGMEngine.begin(&file))
    {
      printlnw(VGMEngine.gd3.enGameName);
      printlnw(VGMEngine.gd3.enTrackName);
      printlnw(VGMEngine.gd3.enSystemName);
      printlnw(VGMEngine.gd3.releaseDate);
      drawOLEDTrackInfo();
      setISR();
      return true;
    }
    else
    {
      Serial.println("Header Verify Fail");
      goto fail;
    }
  }

  fail:
  setISR();
  return false;
}

//Count at 44.1KHz
void tick()
{
  VGMEngine.tick();
}

//Poll the serial port
void handleSerialIn()
{
  while(Serial.available())
  {
    pauseISR();
    char serialCmd = Serial.read();
    switch(serialCmd)
    {
      case '+':
        startTrack(NEXT);
      break;
      case '-':
        startTrack(PREV);
      break;
      case '*':
        startTrack(RND);
      break;
      case '/':
        playMode = SHUFFLE;
        drawOLEDTrackInfo();
      break;
      case '.':
        playMode = LOOP;
        drawOLEDTrackInfo();
      break;
      case '?':
        printlnw(VGMEngine.gd3.enGameName);
        printlnw(VGMEngine.gd3.enTrackName);
        printlnw(VGMEngine.gd3.enSystemName);
        printlnw(VGMEngine.gd3.releaseDate);
      break;
      case '!':
        isOledOn = !isOledOn;
        drawOLEDTrackInfo();
      break;
      case 'r':
      {
        String req = Serial.readString();
        req.remove(0, 1); //Remove colon character
        startTrack(REQUEST, req);
      }
      break;
      default:
        continue;
    }
  }
  Serial.flush();
  setISR();
}

//Check for button input
bool buttonLock = false;
void handleButtons()
{
  bool togglePlaymode = false;
  uint32_t count = 0;
  
  if(!digitalRead(next_btn))
    startTrack(NEXT);
  if(!digitalRead(prev_btn))
    startTrack(PREV);
  if(!digitalRead(rand_btn))
    startTrack(RND);
  if(!digitalRead(option_btn))
    togglePlaymode = true;
  else
    buttonLock = false;
  while(!digitalRead(option_btn))
  {
    pauseISR();
    if(count >= 100) 
    {
      //toggle OLED after one second of holding OPTION button
      isOledOn = !isOledOn;
      drawOLEDTrackInfo();
      togglePlaymode = false;
      buttonLock = true;
      break;
    } 
    delay(10);
    count++;
  }
  if(buttonLock)
  {
    togglePlaymode = false;
    setISR();
  }

  if(togglePlaymode)
  {
    togglePlaymode = false;
    if(playMode == SHUFFLE)
      playMode = LOOP;
    else if(playMode == LOOP)
      playMode = IN_ORDER;
    else if(playMode == IN_ORDER)
      playMode = SHUFFLE;

    if(playMode == LOOP)
    {
      VGMEngine.maxLoops = 0xFFFF;
    }
    else
    {
      VGMEngine.maxLoops = maxLoops;
    }
    
    drawOLEDTrackInfo();
    setISR();
  }
}

void loop()
{    
  while(!VGMEngine.play()) //needs to account for LOOP playmode
  {
    if(Serial.available() > 0)
      handleSerialIn();
    handleButtons();
  }
  //Hit max loops and/or VGM exited
  if(playMode == SHUFFLE)
    startTrack(RND);
  if(playMode == IN_ORDER)
    startTrack(NEXT);
}

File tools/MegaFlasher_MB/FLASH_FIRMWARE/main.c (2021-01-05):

/*
  stm32flash - Open Source ST STM32 flash program for *nix
  Copyright 2010 Geoffrey McRae <geoff@spacevs.com>
  Copyright 2011 Steve Markgraf <steve@steve-m.de>
  Copyright 2012-2016 Tormod Volden <debian.tormod@gmail.com>
  Copyright 2013-2016 Antonio Borneo <borneo.antonio@gmail.com>

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
  You should have received a copy of the GNU General Public License
  along with this program; if not, write to the Free Software
  Foundation, Inc., 51 Franklin Street, Fifth Floor, Boston, MA  02110-1301, USA.
*/

#include <sys/types.h>
#include <sys/stat.h>
#include <stdint.h>
#include <stdio.h>
#include <stdlib.h>
#include <unistd.h>
#include <string.h>

#include "init.h"
#include "utils.h"
#include "serial.h"
#include "stm32.h"
#include "parsers/parser.h"
#include "port.h"

#include "parsers/binary.h"
#include "parsers/hex.h"

#define VERSION "0.5"

/* device globals */
stm32_t		*stm		= NULL;

void		*p_st		= NULL;
parser_t	*parser		= NULL;

/* settings */
struct port_options port_opts = {
	.device			= NULL,
	.baudRate		= SERIAL_BAUD_57600,
	.serial_mode		= "8e1",
	.bus_addr		= 0,
	.rx_frame_max		= STM32_MAX_RX_FRAME,
	.tx_frame_max		= STM32_MAX_TX_FRAME,
};

enum actions {
	ACT_NONE,
	ACT_READ,
	ACT_WRITE,
	ACT_WRITE_UNPROTECT,
	ACT_READ_PROTECT,
	ACT_READ_UNPROTECT,
	ACT_ERASE_ONLY,
	ACT_CRC
};

enum actions	action		= ACT_NONE;
int		npages		= 0;
int             spage           = 0;
int             no_erase        = 0;
char		verify		= 0;
int		retry		= 10;
char		exec_flag	= 0;
uint32_t	execute		= 0;
char		init_flag	= 1;
char		force_binary	= 0;
char		reset_flag	= 0;
char		*filename;
char		*gpio_seq	= NULL;
uint32_t	start_addr	= 0;
uint32_t	readwrite_len	= 0;

/* functions */
int  parse_options(int argc, char *argv[]);
void show_help(char *name);

static const char *action2str(enum actions act)
{
	switch (act) {
		case ACT_READ:
			return "memory read";
		case ACT_WRITE:
			return "memory write";
		case ACT_WRITE_UNPROTECT:
			return "write unprotect";
		case ACT_READ_PROTECT:
			return "read protect";
		case ACT_READ_UNPROTECT:
			return "read unprotect";
		case ACT_ERASE_ONLY:
			return "flash erase";
		case ACT_CRC:
			return "memory crc";
		default:
			return "";
	};
}

static void err_multi_action(enum actions new)
{
	fprintf(stderr,
		"ERROR: Invalid options !\n"
		"\tCan't execute \"%s\" and \"%s\" at the same time.\n",
		action2str(action), action2str(new));
}

static int is_addr_in_ram(uint32_t addr)
{
	return addr >= stm->dev->ram_start && addr < stm->dev->ram_end;
}

static int is_addr_in_flash(uint32_t addr)
{
	return addr >= stm->dev->fl_start && addr < stm->dev->fl_end;
}

/* returns the page that contains address "addr" */
static int flash_addr_to_page_floor(uint32_t addr)
{
	int page;
	uint32_t *psize;

	if (!is_addr_in_flash(addr))
		return 0;

	page = 0;
	addr -= stm->dev->fl_start;
	psize = stm->dev->fl_ps;

	while (addr >= psize[0]) {
		addr -= psize[0];
		page++;
		if (psize[1])
			psize++;
	}

	return page;
}

/* returns the first page whose start addr is >= "addr" */
int flash_addr_to_page_ceil(uint32_t addr)
{
	int page;
	uint32_t *psize;

	if (!(addr >= stm->dev->fl_start && addr <= stm->dev->fl_end))
		return 0;

	page = 0;
	addr -= stm->dev->fl_start;
	psize = stm->dev->fl_ps;

	while (addr >= psize[0]) {
		addr -= psize[0];
		page++;
		if (psize[1])
			psize++;
	}

	return addr ? page + 1 : page;
}

/* returns the lower address of flash page "page" */
static uint32_t flash_page_to_addr(int page)
{
	int i;
	uint32_t addr, *psize;

	addr = stm->dev->fl_start;
	psize = stm->dev->fl_ps;

	for (i = 0; i < page; i++) {
		addr += psize[0];
		if (psize[1])
			psize++;
	}

	return addr;
}

int main(int argc, char* argv[]) {
	struct port_interface *port = NULL;
	int ret = 1;
	stm32_err_t s_err;
	parser_err_t perr;
	FILE *diag = stdout;

	fprintf(diag, "stm32flash " VERSION "\n\n");
	fprintf(diag, "http://stm32flash.sourceforge.net/\n\n");
	if (parse_options(argc, argv) != 0)
		goto close;

	if ((action == ACT_READ) && filename[0] == '-') {
		diag = stderr;
	}

	if (action == ACT_WRITE) {
		/* first try hex */
		if (!force_binary) {
			parser = &PARSER_HEX;
			p_st = parser->init();
			if (!p_st) {
				fprintf(stderr, "%s Parser failed to initialize\n", parser->name);
				goto close;
			}
		}

		if (force_binary || (perr = parser->open(p_st, filename, 0)) != PARSER_ERR_OK) {
			if (force_binary || perr == PARSER_ERR_INVALID_FILE) {
				if (!force_binary) {
					parser->close(p_st);
					p_st = NULL;
				}

				/* now try binary */
				parser = &PARSER_BINARY;
				p_st = parser->init();
				if (!p_st) {
					fprintf(stderr, "%s Parser failed to initialize\n", parser->name);
					goto close;
				}
				perr = parser->open(p_st, filename, 0);
			}

			/* if still have an error, fail */
			if (perr != PARSER_ERR_OK) {
				fprintf(stderr, "%s ERROR: %s\n", parser->name, parser_errstr(perr));
				if (perr == PARSER_ERR_SYSTEM) perror(filename);
				goto close;
			}
		}

		fprintf(diag, "Using Parser : %s\n", parser->name);
	} else {
		parser = &PARSER_BINARY;
		p_st = parser->init();
		if (!p_st) {
			fprintf(stderr, "%s Parser failed to initialize\n", parser->name);
			goto close;
		}
	}

	if (port_open(&port_opts, &port) != PORT_ERR_OK) {
		fprintf(stderr, "Failed to open port: %s\n", port_opts.device);
		goto close;
	}

	fprintf(diag, "Interface %s: %s\n", port->name, port->get_cfg_str(port));
	if (init_flag && init_bl_entry(port, gpio_seq) == 0)
		goto close;
	stm = stm32_init(port, init_flag);
	if (!stm)
		goto close;

	fprintf(diag, "Version      : 0x%02x\n", stm->bl_version);
	if (port->flags & PORT_GVR_ETX) {
		fprintf(diag, "Option 1     : 0x%02x\n", stm->option1);
		fprintf(diag, "Option 2     : 0x%02x\n", stm->option2);
	}
	fprintf(diag, "Device ID    : 0x%04x (%s)\n", stm->pid, stm->dev->name);
	fprintf(diag, "- RAM        : %dKiB  (%db reserved by bootloader)\n", (stm->dev->ram_end - 0x20000000) / 1024, stm->dev->ram_start - 0x20000000);
	fprintf(diag, "- Flash      : %dKiB (size first sector: %dx%d)\n", (stm->dev->fl_end - stm->dev->fl_start ) / 1024, stm->dev->fl_pps, stm->dev->fl_ps[0]);
	fprintf(diag, "- Option RAM : %db\n", stm->dev->opt_end - stm->dev->opt_start + 1);
	fprintf(diag, "- System RAM : %dKiB\n", (stm->dev->mem_end - stm->dev->mem_start) / 1024);

	uint8_t		buffer[256];
	uint32_t	addr, start, end;
	unsigned int	len;
	int		failed = 0;
	int		first_page, num_pages;

	/*
	 * Cleanup addresses:
	 *
	 * Starting from options
	 *	start_addr, readwrite_len, spage, npages
	 * and using device memory size, compute
	 *	start, end, first_page, num_pages
	 */
	if (start_addr || readwrite_len) {
		start = start_addr;

		if (is_addr_in_flash(start))
			end = stm->dev->fl_end;
		else {
			no_erase = 1;
			if (is_addr_in_ram(start))
				end = stm->dev->ram_end;
			else
				end = start + sizeof(uint32_t);
		}

		if (readwrite_len && (end > start + readwrite_len))
			end = start + readwrite_len;
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

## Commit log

2018-03-07 Starting to port code to STM32 platform
2018-03-07 FM Portion of player works. PCM samples are causing issues with external SPI RAM.
    [main.cpp]
2018-04-02 Fixed PCM/RAM bug. STM32 plays vgm music, but seems to be a tad too slow for consistent playback.
    [main.cpp]
2018-04-22 Added OLED support. Beginning schematic
    [STM32_MegaBlaster.kicad_pcb, STM32_MegaBlaster.sch]
2018-04-23 Saving schematic. Nearly Complete
    [STM32_MegaBlaster.sch]
2018-04-23 Schematic complete. Now working on PCB
    [STM32_MegaBlaster.kicad_pcb, STM32_MegaBlaster.sch]
2018-04-27 PCB near complete
    [STM32_MegaBlaster.kicad_pcb, STM32_MegaBlaster.sch]
2018-04-28 PCB Complete
    [STM32_MegaBlaster.csv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]
2018-05-02 Moved gnd trace
    [STM32_MegaBlaster-B.Cu.gbr, STM32_MegaBlaster-B.Mask.gbr, STM32_MegaBlaster-B.SilkS.gbr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]
2018-05-05 Correct amplifier circuit and changed a couple footprints
    [STM32_MegaBlaster-B.Cu.gbr, STM32_MegaBlaster-B.Mask.gbr, STM32_MegaBlaster-B.SilkS.gbr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]
2018-05-05 Corrected headphone jack
    [STM32_MegaBlaster-B.Cu.gbr, STM32_MegaBlaster-B.Mask.gbr, STM32_MegaBlaster-B.SilkS.gbr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]
2018-05-07 Changed diode to more friendly package, moved OLED I2C lines far away from mixer circuit
    [STM32_MegaBlaster-B.Cu.gbr, STM32_MegaBlaster-B.Mask.gbr, STM32_MegaBlaster-B.SilkS.gbr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]
2018-05-12 Fixed PCM and loop offset
    [main.cpp]
2018-05-14 Readme and schematic plots
2018-05-18 Added better BOM
    [DIGIKEY-BOM.csv, STM32_MegaBlaster.csv, STM32_MegaBlaster.sch]
2018-05-19 Updated schematics and gerber files
    [STM32_MegaBlaster-B.Cu.gbr, STM32_MegaBlaster-B.Mask.gbr, STM32_MegaBlaster-B.SilkS.gbr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]
2018-05-20 Comment correction and changed SPI mode for SD card
    [main.cpp]
2018-06-04 Changed playmode indicators and turned off unused LTC6904 inverted outputs.
    [main.cpp]
2018-06-04 Added SN76489 reset in setup to prevent rogue noises on startup
    [main.cpp]
2018-06-10 Changed BOM to include 1000uF capacitors that fit a little better
    [DIGIKEY-BOM.csv]
2018-06-10 Corrected L4, L5 Inductor. 22uH to 2.2mH
    [DIGIKEY-BOM.csv, STM32_MegaBlaster.sch]
2018-07-09 Fixed random song crash if only one track is present on SD card.
    [main.cpp]
2018-07-29 + local RAM PCM Buffer to help speed up songs with small PCM sample sizes.
2018-08-25 Replaced private BOM link with public cart link
2018-09-07 Added interactive HTML BOM guide
    [STM32_MegaBlaster.sch]
2018-09-07 Added info on new interactive BOM
2018-10-28 Cleaned up soundchip drivers and added new bus system
2018-10-29 Saving. Need to fix loop still
    [main.cpp]
2018-10-30 VGM header read, loop adjust. Need to rewrite RAM driver for SEQ reading
2018-10-31 loop glitch fixed. Added loop prebuffer. Added RAM precache
    [main.cpp]
2018-11-01 Added button + serial control. Proper VGM header reading. VGM indent check. Added track navigation
2018-11-01 Added chip resets and clock adjusting after every file load
    [main.cpp]
2018-11-01 Moved command playback to tick interrupt. Various bug fixes
    [main.cpp]
2018-11-02 Fixed crash due to serial call in interrupt. Need to fix odd error'd out command bytes
    [main.cpp]
2018-11-02 Fixed crash on VGM files that were smaller than the main buffer
    [main.cpp]
2018-11-04 New ring buffer. Loop crash fixed. Non-looping VGMs have issues on loop
    [main.cpp]
2018-11-05 New logo, OLED support in. bug fixes.
    [main.cpp]
2019-02-05 Fixed SN76489 typo on schematic
    [STM32_MegaBlaster.kicad_pcb, STM32_MegaBlaster.sch]
2019-02-07 Added PIO command for legacy STM32 libs
2019-03-03 Changed local u8g2 to pio edition, removed extra STM32 'platform'
2019-04-10 PSG Noise channel fixed. Hi-hats are back!
    [main.cpp]
2019-05-27 New VGM driver backported
2019-05-29 Fixed accidentally commented portion of bus driver
2019-07-26 Schematic correction
    [STM32_MegaBlaster.sch]
2020-03-28 New meta file remover function to prevent crashs from system files.
    [STM32_MegaBlaster-B.Cu.gbr, STM32_MegaBlaster-B.Mask.gbr, STM32_MegaBlaster-B.SilkS.gbr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]
2020-03-28 New meta file remover function to prevent crashes from system files.
    [main.cpp]
2020-10-18 Corrected vgm parsing error. Smooth brain moment
    [main.cpp]
2021-01-01 New VGM Engine, yay!
    [STM32_MegaBlaster.sch]
2021-01-02 New bug: Device wont play files when in 00 boot in config
    [main.cpp]
2021-01-02 New clock system caused issues with boot pin 00 config. Removing for now.
    [main.cpp]

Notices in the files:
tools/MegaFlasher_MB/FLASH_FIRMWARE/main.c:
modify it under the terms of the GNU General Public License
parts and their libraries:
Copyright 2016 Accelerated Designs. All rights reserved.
